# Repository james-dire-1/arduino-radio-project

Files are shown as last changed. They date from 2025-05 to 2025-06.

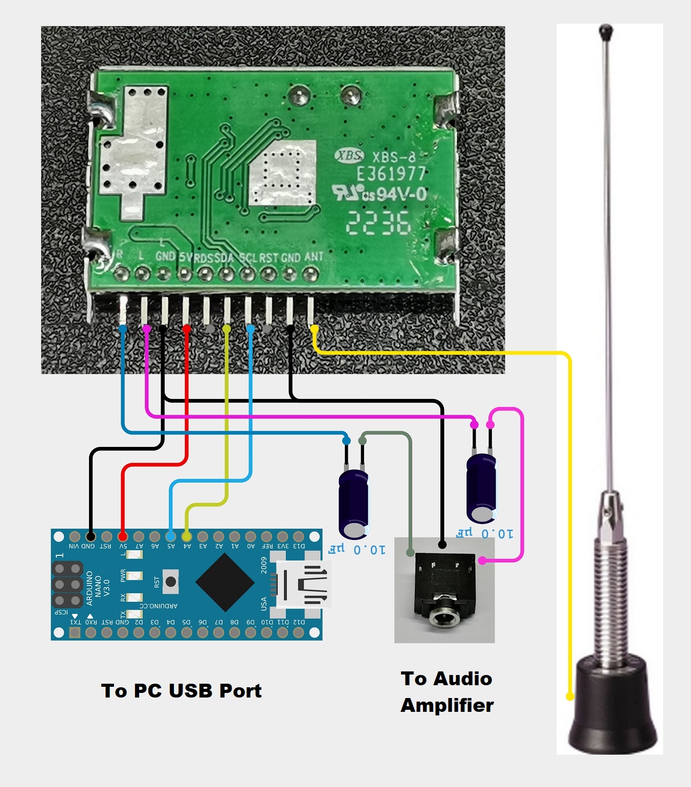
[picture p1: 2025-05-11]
R_other/schematic_final_WVFZMbBmqV.jpg

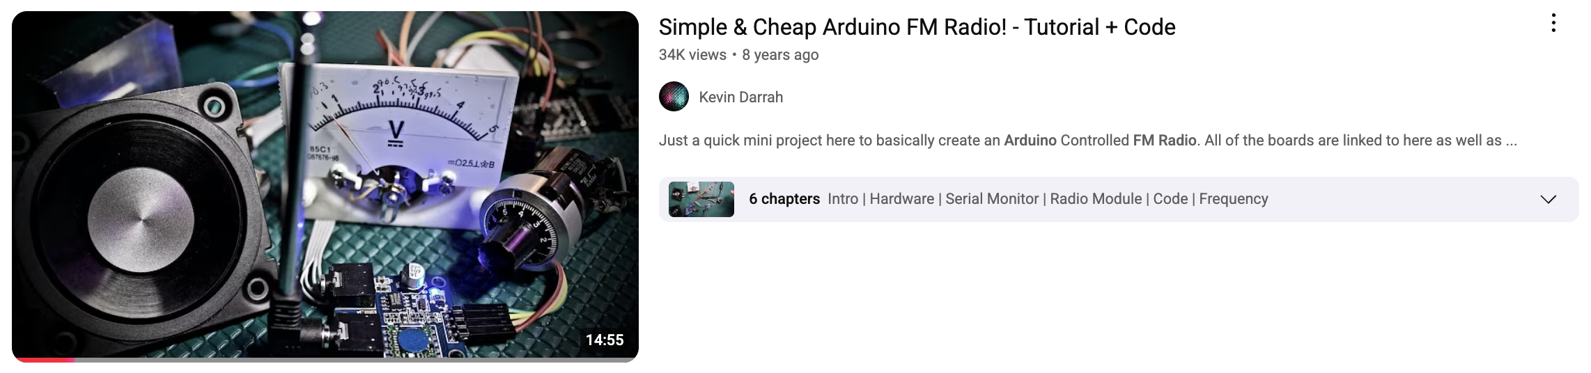
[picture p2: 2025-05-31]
R_other/SlideshowImages/Screenshot 2025-05-30 at 10.30.26 AM.png

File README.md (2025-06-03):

# Arduino Radio

The Arduino Radio is an FM radio built for the Dawson College MakerSPACE Internship as a
semester-long project. It contains an LCD display for displaying band and frequency, supports preset saving and tuning, and is packaged in a small, portable box so that it can be brought around easily. 

## Overview and Features

- Powered by a rechargeable power bank
- Frequency tuning via a rotary encoder
- LCD display for displaying current band and frequency
- Volume control
- Two speakers
- Preset saving
- Last tuned station saved for next power up
- Telescopic antenna
- Green and blue box, with black backplate

## Project Structure

```
arduino-radio-project/
│
├── src/             # Where the code is located
├── R_resources/     # Important resources
├── R_images/        # Images of the final radio
├── R_finalreport/   # The final report for the project
├── R_assignments/   # Formal assignments done for the project (and their iterations)
├── R_slideshow/     # Slideshow for the presentation from May 30th, 2024
├── R_models/        # 3D models for the radio
├── R_oldcode/       # Old iterations of code before version control
├── R_other/         # Miscellaneous files; unimportant
├── R_todo.txt       # General todo list
├── LICENSE          # MIT License file 
└── README.md        # This file
```
There are other files/folders too which were generated by PlatformIO, an extension that enables Arduino support in VSCode, which aren't listed here.

Also, in some of the above folders, there is a `README.txt` file which details all the files/other folders found in that folder.

## Getting Started

Below are instructions for getting the radio working yourself, if you wish.

### Prerequisites

- Visual Studio Code
- The [PlatformIO extension](https://platformio.org/) for VS Code installed
- The libraries outlined below in [Libraries Used](#libraries-used)
- All the necessary hardware (this can be found in [`R_resources/HardwareLinks.txt`](R_resources/HardwareLinks.txt); look under the section MAIN HARDWARE)

### Installation

```
# Clone the repository
git clone https://github.com/james-dire-1/arduino-radio-project.git

# Navigate to project directory
cd arduino-radio-project
```

### Setting things up

⚠️ WARNING: This project overwrites some sections of Arduino EEPROM. Make sure you have nothing important saved in the memory addresses indicated in the code. Also, make sure that the amplifier volume knob is turned down to not have any surprise loud noises on power up.

First, set up the radio circuit as detailed in the circuit diagram (this can be found in [`R_resources/CircuitDiagram.png`](R_resources/CircuitDiagram.png)).
Upload the code onto the Arduino via the Upload tool provided by PlatformIO.
The radio is now ready to go!

### How to use

Extend the antenna for optimal reception. (Although, the radio should still work fine even if the antenna is not extended; it even works without the antenna!)

Use the rotary encoder to switch between frequencies.

Use the joystick to change between presets. Up, down, left, and right correspond to different presets.

Use the knob on the amplifier to change the volume. (But don't raise the volume too high, as audio distortion occurs at high volumes.)

Hold down on the rotary encoder for a few seconds to overwrite any preset. Once the scrolling prompt appears, move the joystick in the direction of the preset you wish to overwrite.

Congratulations, you are now an expert user of the Arduino Radio!

## Advanced Section!

If you would like to package your radio into a portable box, there are model files that can be 3D printed which are found in [`R_models/`](R_models/). However, it is recommended that you design your own box for the radio components, as the designs provided in the model files have many flaws and problems to them.

## Libraries Used

### For LCDs
- [hd44780](https://github.com/duinoWitchery/hd44780/tree/master) by Bill Perry. Contains functions like `setCursor(0, 0)`, `print("")`, and `clear()`

### For rotary encoders
- [RotaryEncoder](https://github.com/mathertel/RotaryEncoder/tree/master) by Matthias Hertel. Contains functions like `tick()` and `getDirection()`

### Extra snippet of code
Also, a snippet of code from Kevin Darrah's YouTube video (linked below in [Videos for inspiration](#videos-for-inspiration)) was used for this project. This code is pasted directly into the RadioModule class. Kevin Darrah mentions in the video that this snippet of code came from Simon Monk's library 
(linked further below).

## Final Report

A final report was written for this project. It can be found in [`R_finalreport/RadioFinalReport.md`](R_finalreport/RadioFinalReport.md).

## License

This Arduino radio project is licensed under the [MIT License](LICENSE).

## Acknowledgments

### Websites for inspration
- [Simple TEF6686 Arduino + PC AM-FM Radio Receiver](https://www.instructables.com/Simple-TEF6686-Arduino-PC-AM-FM-Radio-Receiver/)
- [All Band Receiver With SI4732 / SI4735 (FM / RDS, AM and SSB) With Arduino](https://www.instructables.com/All-Band-Receiver-With-Si4735-FM-RDS-AM-and-SSB-Wi/)

### Videos for inspiration
- [Building a MIDI Controller Using Arduino](https://www.youtube.com/watch?v=JZ5yPdoPooU&t=654s)
- [Make your own FM Radio - Part 1](https://www.youtube.com/watch?v=RqyhvlMKt14) 
- [How To Make FM RADIO using Arduino | TEA5767](https://www.youtube.com/watch?v=Xy7k_ZvcVhU) 
- [Simple & Cheap Arduino FM Radio! - Tutorial + Code](https://www.youtube.com/watch?v=n1hPj2wfsnA) 

### Instructional videos and links used
- [How I2C Communication Works and How To Use It with Arduino](https://www.youtube.com/watch?v=6IAkYpmA1DQ)
- [Using LCD Displays with Arduino](https://www.youtube.com/watch?v=wEbGhYjn4QI)
- [Using Rotary Encoders with Arduino](https://www.youtube.com/watch?v=V1txmR8GXzE)
- [ROTARY ENCODER WITH INTERRUPTS - Arduino tutorial #12](https://www.youtube.com/watch?v=gPLpPFmv-Zc) (not really used)
- [Pin Change Interrupts](https://gammon.com.au/forum/?id=11488&reply=6#reply6) (not really used)
- [Powering Arduino With a Battery](https://www.instructables.com/Powering-Arduino-with-a-Battery/)
- [How to program Arduino with VSCode](https://www.youtube.com/watch?v=gQ2lsSuXvVU)
- [A guide to EEPROM](https://docs.arduino.cc/learn/programming/eeprom-guide/)
- [C++ Tutorial Series](https://www.youtube.com/playlist?list=PLlrATfBNZ98dudnM48yfGUldqGD0S4FFb)

## Plans for Future Expansion

At the moment, there are no plans for future expansion. However, if we do come back to it (of which there is a fair chance of happening), we will attempt to add support for the features that we didn't get the chance to add throughout the semester, which include:

- AM and shortwave support
- Station scanning
- RDS (allows for printing of song title and station name)
- Bluetooth connectivity (so you can listen to songs from your phone, if you don't like whatever is playing on the radio for whatever reason)
- A settings screen with various options for audio
- More presets!

## Libraries We May Consider Using

There exist some libraries that could be useful for the future expansion.

### For TEA5767 FM module
- [Radio by Matthias Hertel](https://github.com/mathertel/Radio) 
- [arduino_TEA5767 by Simon Monk](https://github.com/simonmonk/arduino_TEA5767) 

### For TEF6686 AM and FM module
- [TEF6686Library by ciuri](https://github.com/ciuri/TEF6686Library) (seems to be particularly useful!)

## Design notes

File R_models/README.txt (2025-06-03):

This folder is for all 3D model files of the radio.

Files in this folder (R_models):

Any stl file prefixed with "Old..." in this folder is an old model file for only one face of 
the radio.

Main_box_assembly_part.SLDPRT
    File that was used to combine five different faces from the files prefixed with "Old..."

Main_box_assembly.SLDASM
    Edits on the Main_box_assembly_part.SLDPRT file.

radio_case_assembly.SLDASM
    Edits on the Main_box_assembly_part.SLDPRT file.

Main_box_assembly_part.STL
    The file that was used to print with the 3D printer. If you want to print from one of
    our models (and not make your own) should you want to make the radio yourself, it is
    recommended that you print from this file specifically.

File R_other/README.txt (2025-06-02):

This folder is for miscellaneous files that are related to the radio project, and are only in
this repository for completeness' sake.

Files and folders in this folder (R_other):

schematic_final_WVFZMbBmqV.jpg
    Schematic file we were considering using with the TEF6686 radio module.
    From https://www.instructables.com/Simple-TEF6686-Arduino-PC-AM-FM-Radio-Receiver/ 

ArduinoIdeas.txt
    Notes document used very early on in the project to organize ideas. This file was created
    before the radio idea was decided upon, so there are also other ideas listed.

Radio.ino.txt
    Code from Kevin Darrah's YouTube video https://www.youtube.com/watch?v=n1hPj2wfsnA, which 
    was used mostly as-is for this project. This video also served as inspiration for this
    project. In the video, Kevin Darrah mentions that this specific snippet of code was from
    Simon Monk's TEA5767 library (linked in this repsoitory's README).

ArduinoHardwareInstructions.docx
    Instructions document made so that everyone in the team would know how to wire up the
    radio components.

SlideshowImages/
    Folder of the images that were used in the slideshow found in R_slideshow.

CircuitDiagramImages/
    Folder of images used for the circuit diagram found in R_resources. Also contains the links 
    to all images in the circuit diagram.

ProgressVideos/
    Videos sent by James to the rest of the group when various progress throughout the semester
    was made. Real professional-grade videos with exceptional production quality. Also includes
    a couple of videos recorded by Claudio in the physics lab showcasing the radio working.

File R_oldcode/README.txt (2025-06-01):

This folder is for old iterations of the radio code that existed before version control for the
project was set up. They are presented in this folder for completeness in the documentation of
this project.

Folders in this folder (R_oldcode):

RadioIdeas
    Old project folder from the Arduino IDE from March 16.

RadioIdeas2
    Old project folder from the Arduino IDE from May 1.

RadioIdeas4_1
    Old backup folder from the Arduino IDE from May 8. This backup mostly separated the code into
    multiple files.

RadioIdeas4
    Old project folder from the Arduino IDE from May 10.

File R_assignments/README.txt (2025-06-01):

This folder is for assignments that needed to be submitted (and some of their in-progress 
iterations).

Files in this folder (R_assignments):

project-proposal_DiRe-Scione-Kikia.docx
    The original project proposal outlining the team's project of building an Arduino radio.
    Submitted by March 10th.

OLD_Arduino_Report.docx
    First iteration of the final report.

1_ArduinoReport.docx
    Second iteration of the final report.

2_ArduinoReport.docx
    Third iteration of the final report.

ArduinoReport.docx
    Last iteration of the final report before it was transferred to a Markdown file. The
    most up-to-date report can be found in R_finalreport.

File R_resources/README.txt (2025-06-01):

This folder is for important resources. Most of these resources will be linked from the 
main README file.

Files in this folder (R_resources):

HardwareLinks.txt
    Comprehensive list of hardware for the project along with respective links.

CircuitDiagram.png
    Complete circuit diagram for building the radio. Made with LucidChart.

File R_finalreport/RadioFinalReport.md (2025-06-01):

James R. Di Re, Abdulrahman Kikia, Claudio Scione

June 1<sup>st</sup>, 2025

MakerSPACE Internship

# Arduino Radio - Final Report

## Introduction

In this report, we will detail the brainstorming, designing, programming and building of our MakerSPACE internship project: an Arduino-powered FM radio. Over the course of the past three months, we have worked to put together a working radio while documenting the entire process to serve as an inspiration and as a guide to anyone else who may want to embark on a similar project. Our goal when choosing this as our project was not only to improve our programming and debugging skills through a hands-on approach, but also to gain an understanding of radio waves, audio processing, and speakers. All this, in addition to enjoying the satisfaction of listening to music and news from local radio stations through a compact device we made from scratch.

## Project Description

### Objective

The goal of this project was to build a working AM/FM radio, using the Arduino Uno as the microcontroller and the Arduino IDE to write the code. We aimed to not only have it be able to play music through speakers, but also to display information about the frequency and station (RDS) on a digital display. Finally, we wanted to design and build a casing to insert all the hardware into that was practical and portable. While this was the base goal of this project, we hoped to add as many features as possible to the radio within the time frame we had to complete this project. We hoped to add a function to save preset radio stations that you could choose and change as you wished, shortwave compatibility, radio station scanning and even Bluetooth connectivity.

### Inspiration

It was James who originally came up with the idea of making a radio using Arduino. He knew initially that he wanted to do something involving audio, since he always enjoyed working with music and had a fascination with how sound waves worked. At first, he looked through many different audio projects, such as synthesizers, MIDI controllers, and distortion-altering guitars, but there was one common problem with all of these projects: none of us knew anything regarding these topics. Eventually, he saw a few videos on YouTube of people using Arduinos to make working radios. A radio project seemed more feasible than other audio projects he had seen, since everyone in the team was familiar with how radios worked. However, the videos used FM-only radio modules, and only detailed the wiring process. We decided it would be interesting to expand on those projects James had seen online to make a radio with more features and a case to enclose it in. After some research on the Arduino forums, Instructables, and other project sites, we saw other examples of radios, each with their own unique construction and design. That made us realize that this was something we could realistically build and design on our own in the months we had to work on this project. Plus, the fact that the radio was practical (we could listen to music and news from it everyday) and intuitive (you can pick up radio signals anywhere) solidified our decision.

### Design and Planning

For the design, we wanted to build a radio that was reminiscent of old-school radios. That is, we wanted to use knobs instead of buttons. We also wanted it to be unique with some asymmetry. We shared different sketches of the design and some concept 3D renders to see where our imagination could go. In the end, we couldn’t settle on a specific design until we got all parts working and tested.

Much research was done early on to figure out the exact parts we were going to need. Also, the sheer number of available radio modules to pick from was overwhelming. However, one common theme between the videos we had initially watched was that most of them used the TEA5767 FM-only module, so we decided to get that in case other modules didn’t work the way we wanted them to. It was a logical decision, since if many others had success with it, then we should have success with it too. However, our initial goal was to have an AM/FM radio, with possible support for shortwave too, so we continued looking for more radio modules. After some more research, we were leaning towards the Si4732, which seemed to be very advanced and had many features to it. However, upon digging deeper, we realized that this “radio module” was nothing more than an extremely tiny chip; no breakout board for ease-of-use with Arduino existed. Thus, we had to keep looking.

An easy-to-use AM and FM radio module seemed to be nonexistent, but then James saw a YouTube video of an AM and FM Arduino-powered radio, so then we realized that one must exist. This new video we found pointed us in the direction of the TEF6686 module. This had most of the advantages of the Si4732 but had a sort of breakout component that could be used with our Arduino, with the help of pitch changers. However, there were less chances of this module being successful for us, since there were less people online who had used it, there was overall less documentation for it, and the pinout seemed a lot more complicated compared to that of the TEA5767 (we found only a single circuit diagram explaining how the pinout worked). So, we decided that we would try first with the TEA5767, and if we had time, we would try the TEF6686.

Designing a case to house all the parts also proved to be a challenge. The setup out of the case functioned well, but was fragile in the initial phases. The speaker wires kept disconnecting from the amplifier with the slightest movement, thus causing the speakers to stop playing, even after tightening the screws to hold the wires in place. To fix this, a thicker wire was soldered onto the thinner speaker wire. There were also pieces that would have to be mounted to the front of the case, so that the user could interact with the radio as intended. This was particularly problematic for the speakers, since they didn't have screw holes. Also, their wires could interfere with the screen if the positioning wasn’t optimal. However, the screen, antenna, and rotary encoder had screw holes, so mounting them wouldn’t be an issue. We made a prototype using cardboard to see how the pieces would go together. With the prototype, we attempted to make measurements for where each of the components would go, and then Abdulrahman incorporated these measurements in the modelling software he was using by adding holes to the box design where necessary. 

Initially the idea was to have the six faces of the box snap into each other through connectors that were meant to hold them by pressure. However, as the faces would break with high pressure, we had to change the design so that five faces would be permanently attached (one only would be detachable). 

As for our power source, we planned out different options. We thought of using a 9-V battery, but the connector that the battery used was very stiff and didn't come easily out of its terminals, so removing the battery wasn’t a feasible option to cut the circuit. After trying different options, we ended up using a power bank, as it can be easily removed and charged when needed. 

The result of all this planning was a radio that was fairly portable, and was comparable to other radios of its kind in size.

## Implementation

### Hardware Setup

#### Hardware List

- Arduino Uno microcontroller
- Rotary encoder with button - for frequency tuning
- LCD display that is I<sup>2</sup>C compatible - for displaying radio data
- TEA5767 FM radio module with antenna - for receiving radio signals
- TDA7297 amplifier - for amplifying the audio signal coming from the radio module and for allowing volume control
- Male-to-male headphone wire - for sending the audio signal from the radio module to the amplifier
- Speakers
- Joystick - for choosing between different preset stations (up, down, left, right = 4 presets)
- Power source: power bank OR 9-V battery OR power from a computer
- Male-to-male jumper wires
- Male-to-female jumper wires
- Breadboard

#### Circuit Diagram

Circuit Diagram

### Software Development

#### Process

Firstly, James already had C++ knowledge from a tutorial series he had watched on YouTube a few years ago by The Cherno, so because of that, it was a lot easier for him to write code for the project compared to someone just starting out. However, this was still his first time putting that knowledge into real practice. James recommended to the other group members that they watch some videos from the tutorial series too. 

The features in the code were at first programmed in the Arduino IDE, and were added gradually (for example, first the code for the rotary encoder and LCD display were added, then the code for the radio module, then the code for the joystick, then the code for preset-saving, etc.). The code was always kept in a maintainable condition that was simple to expand upon. This was a top priority, as James knew from past projects that untidy code gets exponentially hard to maintain. Eventually, even though the code was kept organized, it was still overwhelming to keep all the functionality in one file. Thus, it was separated into six separate files: the main cpp file, a main header file, a class for managing radio state, a class for handling input, a class for handling the LCD display, and a class for handling the radio module. Later on in development, this proved to be a great choice, as each of these files grew in size. Looking back, it would not have been feasible to have kept everything in a single file. 

However, separating the code into different files didn’t come without its own problems. For one thing, there were many bugs that got introduced as a result, and all of them were isolated to being issues regarding C++’s copying of objects in unexpected areas. As a result, in fixing these bugs, the team grew more familiar with C++’s copying conventions, and became more aware of when it was appropriate to use pointers (`*`) or references (`&`).

Eventually, the entirety of the code was moved to Visual Studio Code. This provided many advantages over the Arduino IDE. For one thing, VS Code allowed for easy integration with version control software such as Git and GitHub. Also, it underlined compilation errors in real-time, a feature which the Arduino IDE lacks entirely. There were also refactoring tools and an easy way to view the project structure. The extension used that introduced Arduino compatibility in VS Code was PlatformIO. A GitHub repository for the project was created.

Once everything was in VS Code, all the old iterations of code we had which were not under version control were pushed to the GitHub repository in a separate folder. This was in an effort to document everything we could. However, all new code added to the project was properly pushed to GitHub in the proper fashion, with frequent commits.

New functionality for the radio kept getting added until just a few days before the MakerSPACE presentation on May 30<sup>th</sup>. Once the code was entirely done, James looked through all of it one last time to see if any little details could be improved upon, then committed and pushed the changes. This was the code iteration that was used in the in-class demo. 

#### Libraries

As for libraries, a couple of them were used. First, there was `hd44780` by Bill Perry, an LCD library using I<sup>2</sup>C communication, which was exactly what we needed, since the LCD screen we had purchased supported I<sup>2</sup>C communication through a little board on the back. Also, this library was supposedly more up-to-date and compatible with more LCD models than other libraries, even those that had been around for a long time. Since this library was meant to be easy-to-use for those that were already familiar with other, more-established LCD libraries, many of the function names matched those from other libraries. Some useful functions include `setCursor(int, int)`, `print(“”)`, and `clear()`.

The other library that was used was `RotaryEncoder` by Matthias Hertel. This library saved us a lot of headache, since it removed the problem of trying to find a good way to read the quickly changing voltages from the data and clock pins on our rotary encoder to determine the direction of turning. Also, all code that I had seen for this task was flawed in some way. Thus, this library did a lot of the heavy lifting for us. However, one minor issue with it was that input needed to be polled very frequently in order to catch all turns done on the rotary encoder. This meant that we had to ensure that our `loop()` function was kept short, and was short to execute. Sometimes, during debug sessions where we had `Serial.println()` calls scattered throughout the code, the rotary encoder would become completely unresponsive. Nonetheless, the library did get the job done. Some useful functions include `tick()` and `getDirection()`.

Also, although not really a library, a snippet of code from one of Kevin Darrah’s YouTube videos was used, which communicated desired frequency values to the radio module. This code was pasted directly into our code, and was left mostly as-is. Kevin Darrah mentions in his video that the code is from a TEA5767 library by Simon Monk.

An important reference that helped us frequently was the official Arduino documentation. For instance, everything we needed to know about EEPROM was included in the documentation, and was presented in a clear, concise manner. In addition, as mentioned earlier, the YouTube tutorial series by The Cherno was occasionally consulted throughout development.

### Sensor Documentation

- TEA5767 Radio Module

The radio module picks up FM radio signals. Signal reception is improved when an antenna is attached. To communicate with the radio module, which uses I<sup>2</sup>C, we need to use the Arduino `Wire` library. 

The following is the code provided by Kevin Darrah in his YouTube video (mentioned earlier) to communicate with the radio module to change stations. 

```arduino
void setFrequency(float frequency)
{
  // The calculation that needs to be performed before sending the frequency is outlined in the datasheet for the TEA5767
  unsigned int frequencyB = 4 * (frequency * 1000000 + 225000) / 32768;
  
  // Getting the high byte of the modified frequency
  byte frequencyH = frequencyB >> 8; 
  // Getting the low byte of the modified frequency
  byte frequencyL = frequencyB & 0XFF; 

  Wire.beginTransmission(0x60); // Begin communication with the radio 
  Wire.write(frequencyH); // Writing high byte
  Wire.write(frequencyL); // Writing low byte

  // The following three bytes that are written correspond to a set of parameters being sent to the radio module. Generally, each bit indicates a setting for the radio module to follow. The exact details of each bit in each byte are found on the datasheet.
  Wire.write(0xB0);
  Wire.write(0x12);
  Wire.write(0x00);

  Wire.endTransmission(); // End communication
  delay(100);
}
```

- TDA7297 Amplifier

The amplifier detects sound signals (from the radio module) and transmits them to the speakers. It also has a potentiometer that controls the power given to the speaker (the volume coming out of them).

- Rotary Encoder

The rotary encoder helps with navigating radio frequencies. Each step in the rotation gives the Arduino a signal to either increase or decrease the frequency picked from the radio module by 0.2 MHz, which is the standard for radio stations in Montreal. The rotary encoder works by taking into account the voltage patterns over time across the data wire and the clock wire. With this information, we can deduce which way the rotary encoder is being turned. However, the way to deduce this is slightly complicated, so a rotary encoder library is used. 

Code to initialize a `RotaryEncoder` object with the `RotaryEncoder` library:

```arduino
// PIN_A and PIN_B refer to the clock and data lines of the rotary encoder. If the rotary encoder behaviour is opposite to what you expect, just switch these pins in the constructor.
RotaryEncoder encoder(PIN_A, PIN_B, RotaryEncoder::LatchMode::FOUR3);
```

Code to poll rotary encoder input (should be called every time `loop()` is run):

```arduino
encoder.tick();
```

Code to get the direction that the rotary encoder has turned:

```arduino
// Returns 0 if not turning, 1 if clockwise, -1 if counterclockwise
int direction = encoder.getDirection();
```

- Joystick

The joystick has two potentiometers for dual axis rotation. It can detect the rotation of the stick in a continuous manner (but only four directions with precision) and in our case is the optimal way to select and tune in on presets. Input is read via the analog pins.

Code for reading in the x and y values of the joystick, which range from 0 to 1023:

```arduino
int rawX = analogRead(PIN_X);
int rawY = analogRead(PIN_Y);
```

Code to convert these values to those that are between -1 and 1, which are a lot easier to work with:

```arduino
float x = (rawX / 1023.0f) * 2 - 1;
float y = (rawY / 1023.0f) * 2 - 1;
```

## Results

At the end of the project, we had a functional radio that was capable of tuning to FM radio stations for extended periods of time, which made it practical for everyday use. In addition, the audio quality was not bad at all. The rotary encoder for changing between stations worked without any problems. The LCD display also showed relevant information, such as band, frequency, and preset number without any problems. We did manage to get preset-tuning and preset-saving to work with the joystick in the last week or two leading up to the final MakerSPACE presentation, although there were some problems involving it (explained a bit later). Also, throughout the development process, up until the end, the code was still well organized, and didn’t get too untidy.

However, there were some persisting issues that lasted until the end of the project. For one thing, every time the LCD screen updated, interference could be heard through the speakers (a static sound). This was not really noticeable when the screen contents changed periodically, but whenever the contents changed frequently (such as when text was scrolling), it would become really noticeable. We were never able to fix this. In addition, there was a similar type of interference issue with the joystick. Whenever moving the joystick (especially in the direction defined as preset 2 in our code), a loud buzzing noise could be heard, and would continue to play until the joystick was let go.

In addition to that, the joystick for some reason interfered significantly with any I<sup>2</sup>C communication, and we never figured out why. We tried including capacitors in our circuit to regulate the problem, but they didn’t have any effect on the issue. Since the joystick would interfere with I<sup>2</sup>C, sometimes missing or strange characters would appear on the LCD screen or the code would freeze. We knew the code froze because we sprinkled our code with `Serial.println()` calls to isolate the issue, and at one point, it would stop printing at a `Serial.println()` call that was right before any `Wire`-related Arduino function. To confirm that it was the joystick causing the problem (and not some other component), we changed the code to switch radio stations every one second instead of changing them via the rotary encoder, and commented out all code involving the joystick. However, we still kept the joystick connected. Under these conditions, whenever the radio station would stop switching, it would always happen when the joystick was being moved around.

Another problem with the radio was that the volume knob couldn't be turned all the way, or very bad distortion would occur.

As for the box, many compromises after printing had to be made. According to Claudio (who printed part of the radio box at his house and whose brother’s friend printed another part at his house), most of the measurements that we had made for fitting everything in the box were wrong. This meant that he and his brother had to come up with creative solutions for getting everything in the box. For instance, our radio’s handle holes (holes at the top to easily hold the radio) turned out to be the holes through which the antenna and Arduino ports were accessible, as the real holes we made for them were not positioned properly. In addition, the breadboard didn’t fit lying flat on the radio’s floor, which was the initial plan, so it had to be placed sideways against the back. Also, the little shelves that were made to place the speakers on were not positioned properly, and so they had to be broken off. Lastly, although our initial plans were to screw all the components in, we ended up hot gluing most of them instead to save on time. To save on more time, the print job was done at twice the intended speed so that the box would be ready on presentation day. This resulted in a battered-up box. However, despite all these drawbacks, the radio was still entirely functional.

### Comparing with Initial Objectives 

Compared to the initial objectives, there were some features that were not achieved for the final product. For instance, the final radio did not support AM or shortwave bands, since we did not have time to try out the TEF6686 radio module, which supported these features. There was also no radio station scanning, RDS, or Bluetooth connectivity. Also, since there wasn’t enough time to design a PCB for the components, we had to stick to the breadboard, which took a lot of space inside the box. Besides these lacking features though, everything else we had planned on was included.

### Discussion and Conclusion

Overall, the project was a lot of fun to work on, and we learnt a lot throughout the semester, such as how to use Git and GitHub, libraries, VS Code, C functions like `sprintf()`, and EEPROM. Also, we learnt how to package components into a box. By the end, we were really excited that we had created our very own radio. 

Most of the successes occurred early on in the project, when we were testing the radio features before packaging everything in a box. Adding more code and testing it went mostly smoothly. We think this was because (like mentioned earlier), James already had prior C++ knowledge before starting the project. Plus, Abdulrahman had also been learning Python on his own for some time, and Claudio learnt some programming in the engineering physics class, so all of us had the knowledge necessary to think in a logical, problem-solving manner. 

Many of the challenges occurred much later in the project, mostly in the last week leading up to the presentation, which was the week when the final box was designed, printed, and altered. None of us had printed 3D models made to house various components that needed to interact with each other before, so we guessed that this part was going to be challenging. Our guess was correct, as many last-minute changes and compromises had to be made due to the bad measurements we had taken. However, while running into mistakes due to measurements is normal, as many of the placements were eyeballed, what really affected us the most was the limited time to print the enclosure and adjust the measurements. There was basically no time to print multiple versions and get the optimal radio enclosure to house all the parts in a neat way, which even the most skilled mechanical engineers would do. So for a first version that was printed in half the required time, it still managed to hold all of the components, and even had a unique look.

Once again, at the beginning of the Winter 2025 semester, we had set an objective for ourselves to build a portable AM and FM radio that included features such as preset-saving, scanning, RDS, and Bluetooth compatibility. The idea to build a radio came from James wanting to do a project involving audio and from watching many YouTube videos of others building Arduino radios. Then, throughout the course of the semester, we gradually obtained more and more hardware to continue expanding upon our radio, adding features as we went. As more features were added, the codebase was split into separate files to maintain control, organization, and scalability. Libraries also facilitated the development process. By the end of the project, we had built a fully functional Arduino radio. Although it did not include every feature that we had planned to implement, we were still really proud of what we created. Not only that, but we also gained much knowledge and skill that can be applied for future projects.

Some possible improvements for the project include those already mentioned that did not make the final build (i.e. AM, shortwave, scanning, RDS, Bluetooth compatibility). In addition, it could be interesting to experiment with different box designs, such as one made out of wood. Potentially, it would be interesting to make the whole chassis thinner and more organized internally by designing a custom PCB. Moreover, we are curious as to how we would go about making a settings menu that supported changing audio settings, such as bass, treble, etc. We’re not sure as to how we could get that to work, since it seems like achieving this feature would mean routing the audio signal through the Arduino, which doesn’t seem feasible since we don’t think the Arduino can process audio signals fast enough for them to still be perceived as good sound, but the idea is still interesting nonetheless.

### References

#### Link to the repository:

https://github.com/james-dire-1/arduino-radio-project 

#### Libraries:

[1] Bill Perry, “hd44780: Extensible hd44780 LCD library,” _GitHub_, 2016. https://github.com/duinoWitchery/hd44780/tree/master (accessed Jun. 01, 2025).

[2] Matthias Hertel, “RotaryEncoder: RotaryEncoder Arduino Library,” _GitHub_, Jul. 18, 2022. https://github.com/mathertel/RotaryEncoder/tree/master (accessed Jun. 01, 2025).

#### Inspiration sources:

[1] mircemk, “Simple TEF6686 Arduino + PC AM-FM Radio Receiver,” _Instructables_, Mar. 31, 2023. https://www.instructables.com/Simple-TEF6686-Arduino-PC-AM-FM-Radio-Receiver/ (accessed Jun. 01, 2025).

[2] pu2clr, “All Band Receiver With SI4732 / SI4735 (FM / RDS, AM and SSB) With Arduino,” _Instructables_, Mar. 26, 2020. https://www.instructables.com/All-Band-Receiver-With-Si4735-FM-RDS-AM-and-SSB-Wi/ (accessed Jun. 01, 2025).

[3] Switch & Lever, “Building a MIDI Controller Using Arduino,” _YouTube_, Dec. 03, 2019. https://www.youtube.com/watch?v=JZ5yPdoPooU (accessed Jun. 01, 2025).

[4] GreatScott!, “Make your own FM Radio - Part 1,” _YouTube_, Mar. 06, 2016. https://www.youtube.com/watch?v=RqyhvlMKt14 (accessed Feb. 13, 2024).

[5] EDISON SCIENCE CORNER, “How To Make FM RADIO using Arduino | TEA5767 | giveaway results,” _YouTube_, Aug. 16, 2024. https://www.youtube.com/watch?v=Xy7k_ZvcVhU (accessed Jun. 01, 2025).

[6] Kevin Darrah, “Simple & Cheap Arduino FM Radio! - Tutorial + Code,” _YouTube_, Dec. 17, 2016. https://www.youtube.com/watch?v=n1hPj2wfsnA (accessed Jun. 01, 2025).

#### Instructional/learning resources:

[1] How To Mechatronics, “How I2C Communication Works and How To Use It with Arduino,” _YouTube_. Oct. 05, 2015. Accessed: Jun. 01, 2025. [YouTube Video]. Available: https://www.youtube.com/watch?v=6IAkYpmA1DQ 

[2] DroneBot Workshop, “Using LCD Displays with Arduino,” _YouTube_. Mar. 19, 2018. Accessed: Jun. 01, 2025. [YouTube Video]. Available: https://www.youtube.com/watch?v=wEbGhYjn4QI

[3] DroneBot Workshop, “Using Rotary Encoders with Arduino,” _YouTube_, Mar. 23, 2019. https://www.youtube.com/watch?v=V1txmR8GXzE (accessed Jun. 01, 2025).

[4] amandaghassaei, “Powering Arduino With a Battery,” _Instructables_. https://www.instructables.com/Powering-Arduino-with-a-Battery/ (accessed Jun. 01, 2025).

[5] Abstract programmer, “How to program Arduino with VSCode,” _YouTube_, Aug. 13, 2022. https://www.youtube.com/watch?v=gQ2lsSuXvVU (accessed Jun. 01, 2025).

[6] “A guide to EEPROM,” _Arduino Docs_, Jun. 19, 2024. https://docs.arduino.cc/learn/programming/eeprom-guide/ (accessed Jun. 01, 2025).

[7] The Cherno, “C++ Series,” _YouTube_. https://www.youtube.com/playlist?list=PLlrATfBNZ98dudnM48yfGUldqGD0S4FFb (accessed Jun. 01, 2025).

### Acknowledgements

Thank you to Abdulrahman’s high school robotics team for allowing him to use software such as Onshape regularly, which allowed him to design the radio box himself.

Thank you to Claudio’s brother and his friend William for printing out our radio, and thank you again to Claudio’s brother for helping come up with solutions to the incorrect measurements we had made.

Thank you to all the instructional/learning resources and libraries listed above. Every one of them helped the radio project come to life.

Thank you to all the inspiration sources also listed above. Without them, we may not even have built a radio.

And a huge thank you to Joel Trudeau and Manuel Zapata for mentoring the MakerSPACE Internship, and thank you to Dawson College for covering some of the costs for hardware. The Friday meetings were really the highlight of the school week! ☺

And thank you to everyone who showcased their projects during the final presentation, effectively encouraging and inspiring everyone to continue working on electronics projects even after the internship concluded.

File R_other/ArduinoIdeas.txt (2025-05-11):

Arduino ideas

// MIDI Controller
// Synthesizer Module
// Posture Corrector
// Stress Level Monitor
Radio
// Water quality thing

Arduino GIGA Wavetable Synthesiser
https://projecthub.arduino.cc/Arduino_Genuino/arduino-giga-wavetable-synthesiser-737364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 
Auduino - Lo-Fi Arduino Synthesizer
https://www.instructables.com/Auduino-Lo-Fi-Arduino-Synthesizer/ 

DIY ESP32 Internet Radio
https://projecthub.arduino.cc/zetro/diy-esp32-internet-radio-4353a4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..
A radio similar to this one seems interesting, but it would have to be modified to use the UNO

Arduino VFO Project with a Large LCD Display
https://projecthub.arduino.cc/mircemk/arduino-vfo-project-with-a-large-lcd-display-6f8e83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 
Doesn’t seem to be useful for us, but it seems like it is able to transmit radio waves, so maybe it might be interesting to look at?

Using Arduino to Test Your Water Quality
https://projecthub.arduino.cc/sharnat/using-arduino-to-test-your-water-quality-3c08dc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. 

BMP280: Measure Temperature, Pressure and Altitude
https://projecthub.arduino.cc/SurtrTech/bmp280-measure-temperature-pressure-and-altitude-6002cd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

SENSORS
1: Joystick
14: Touch sensor?
22: Button
26: Buzzer?
32: Passive buzzer?
34: Rotary encoder

NOTES- Apparently volume control can be handled directly on the amplifier

MAIN PARTS
Main microcontroller: Arduino UNO
Main radio module: Si4732
Speaker: 
Screen: LCD screen

On/off function: 
Volume function: 
AM/FM toggle function:
Tuning function:
Presets function:
Scan function:
Set presets function:

Amplifier: a 5-volt class D amplifier/TDA7297?
Internal volume manager: MCP4151 (potentiometer)
Storage for presets and last station: EEPROM which is built into the UNO (no SD card necessary)
Antenna: telescopic antenna

OTHER PARTS to consider but probably will not be used
Main radio module: TEA5767 (x3) - only supports FM
Amplifier: TDA1905 - too complicated to use

KNOBS
1-turn potentiometer
10-turn potentiometer

// VIDEOS
// https://www.youtube.com/watch?v=RqyhvlMKt14
// https://www.youtube.com/watch?v=n1hPj2wfsnA 

// Si4732
// Si4735
// TEA5767
// TEA5768
// TEF6686

——

Why It is better to use the TEF6686 instead of the Si4732:

Si4732 is actually just a chip. There are not really any modules that are available for our case.
Si4732 does have some breakout boards. At first, I thought these were the actual modules. Then, I realized that they were something that required a lot of soldering to get working. You can either get a breakout board for the Si4732 by looking at a GitHub instruction page and making one yourself, by getting it on PCBWay, or by buying it off a retailer already built.
Si4732 does seem to have some modules, but not any that are useful for our needs. One module already includes an Arduino Nano or something similar with it, which means the module is already a fully functional radio. Another one seemed to be promising, as it had an audio jack similar to the one seen on the TEA5767, but there was a space fitted specifically for an Arduino Nano or something similar, which was also not what we needed. A third one I saw looked like a module (at first I had thought it was a raw chip, but it wasn’t), but it was a module specifically for use with a specific type of walkie talkie from a specific manufacturer. I got suspicious of this when I noticed that the pin locations/soldering locations on the module didn’t even have any indications as to what each of them were for.

Also, if you manage to get one of those breakout boards for the Si4732, there seems to be a lot of work that needs to be done to get it to work with an Arduino. There seems to be a lot of crazy soldering and such. Also, the pin indications on the raw chip don’t even match nicely with the pin indications of the breakout board, which just added to the confusion. Also, the third-party library that is supposed to go with this chip seemed very intimidating to use, due to our inexperience. If we don’t want to use the library, then we would have to read through the data sheet, which is something I really don’t want to do (it is longer than both the TEA5767 and TEF6686’s data sheets). It didn’t seem right to base everything on our trusting the library, since we should have some understanding of what is going on, even if we are using a library. With the TEF6686 however, I found a library that seems straightforward to understand, and once it is understood, we could even understand more deeply the I2C protocol that takes place between the Arduino and the TEF6686. It also helps that the data sheet for the TEF6686 is much more simpler to understand, and is written in a very straightforward way. It is also really nice that the TEF6686 library is very lightweight; it only consists of a few files, so it doesn’t feel like we are leaving all of the work to the library in question.
Also, the schematic for setting up the Si4732 breakout board with the Arduino seems ridiculously complicated to understand. The schematic for setting up the TEA5767 module with the Arduino, and the schematic for setting up the TEF6686 module with the Arduino, seem very straightforward to use, and intuitively make sense in the context of I2C (the Si4732 schematic seemed to be all over the place and impossible to understand). Although the TEF6686 schematic does seem slightly more involved than the TEA5767 schematic, it is not by much.

One good alternative we could have used was the complete module of the Si4732 created by Sparkfun. It seemed to be a complete module and everything. Unfortunately (or fortunately, I don’t know yet), it got discontinued.

We might decide to implement our radio with the TEA5767 before trying out the TEF6686, just because there are already many examples online of people using the TEA5767 (such as in YouTube videos), and so there would be a lot of help and reference should we need it. Also, we already have perfectly working code from a YouTuber if we use the TEA5767; if we use the TEF6686, we would have to rely on the corresponding library at first, which we aren’t even sure would work. However, it would be great to switch to the TEF6686 eventually, just because it also supports AM, which the TEA5767 doesn’t.

Additional functions:

Continuous scan
Settings options
	continuous tuning
	about section
Additional AM/FM button, as pressing on the knob will just show more information

Links:

Websites for inspiration
https://www.instructables.com/Simple-TEF6686-Arduino-PC-AM-FM-Radio-Receiver/ 
https://www.instructables.com/All-Band-Receiver-With-Si4735-FM-RDS-AM-and-SSB-Wi/

Videos for inspiration
https://www.youtube.com/watch?v=JZ5yPdoPooU&t=654s 
https://www.youtube.com/watch?v=RqyhvlMKt14 
https://www.youtube.com/watch?v=Xy7k_ZvcVhU 
https://www.youtube.com/watch?v=n1hPj2wfsnA 

Instructional videos and links
https://www.youtube.com/watch?v=6IAkYpmA1DQ 
https://www.youtube.com/watch?v=wEbGhYjn4QI 
https://www.youtube.com/watch?v=V1txmR8GXzE 
https://www.youtube.com/watch?v=gPLpPFmv-Zc 
https://gammon.com.au/forum/?id=11488&reply=6#reply6 

Instructables
https://www.instructables.com/Powering-Arduino-with-a-Battery/ 

Libraries
TEA5767
https://docs.arduino.cc/libraries/radio/?fbclid=IwAR0RHHBBque7rx_zP_Ns2fzSN8FPqqi5Pc9K1L9mtPytmW70RFdRn7JaiW4 
https://docs.arduino.cc/libraries/arduinotea5767/ 
TEF6686
https://github.com/ciuri/TEF6686Library 
Miscellaneous
https://github.com/RTVDXRO/TEF6686-AM_FM_RDS-Radio/blob/master/UserManualTEF668X.pdf 
https://github.com/jgromes/RadioLib 
For LCDs
https://github.com/duinoWitchery/hd44780/tree/master 
Rotary Encoders
https://github.com/mathertel/RotaryEncoder/tree/master 

Radio modules
https://www.amazon.ca/76-108MHZ-TEA5767-Stereo-Module-Antenna/dp/B074TC3VLN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 
https://www.amazon.ca/Radio-Module-Main-chip-TEF6686/dp/B0DXF17PTN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 

Amplifiers
https://www.amazon.ca/DEVMO-TDA7297-Digital-Amplifier-Channel/dp/B07T5L5GY4 
https://www.amazon.ca/Willwin-PAM8403-Digital-Stereo-Amplifier/dp/B075ZR6QNX 
https://www.amazon.ca/Ganasome-Times-LM386-Amplifier-Module/dp/B0CW193LVD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

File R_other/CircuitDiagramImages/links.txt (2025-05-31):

Links for circuit diagram

https://www.pololu.com/product/2191 
https://learn.sparkfun.com/tutorials/how-to-use-a-breadboard/all 
https://www.circuitbasics.com/how-to-setup-and-program-rotary-encoders-on-the-arduino/ 
https://www.amazon.ca/SunFounder-Serial-Module-Display-Arduino/dp/B019K5X53O?th=1 
https://hub360.com.ng/product/tea5767-fm-radio-module/ 
https://store.fut-electronics.com/products/fm-radio-receiver-module-with-antenna-tea5767 
https://www.amazon.ca/dp/B07T5L5GY4 
https://www.freepik.com/psd/electricity 
https://www.amazon.ca/Arduino-Dual-axis-Joystick-Quality-Control/dp/B07Z453Y4H 
https://icontact-2.myshopify.com/products/2600mah-power-bank-green-210series

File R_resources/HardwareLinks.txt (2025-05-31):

MAIN HARDWARE:

Arduino UNO Microcontroller
Rotary Encoder with Button https://addison-electronique.com/en/iduino-rotary-encoder-module.html 
LCD Display that is I2C compatible 
Tuner Module 1 (FM only) with Antenna (TEA5767) : https://www.amazon.ca/dp/B074TC3VLN
Amplifier 1 (TDA7297) : https://www.amazon.ca/dp/B07T5L5GY4
Male-to-male Headphone Wire : https://www.amazon.ca/dp/B01L0YPVOY
New Speakers : https://www.amazon.ca/gp/product/B07G9ZMYMZ
Joystick : https://addison-electronique.com/en/5-pin-thumb-joystick-module-for-arduino.html 
Power Bank     OR     9V Battery     OR     Power from a Computer
Male-to-male Jumper Wires
Male-to-female Jumper Wires
Breadboard

HARDWARE NO LONGER NEEDED/NOT IN USE:

Tuner Module 2 (FM and AM) (TEF6686) : https://www.amazon.ca/dp/B0DXF17PTN
Amplifier 2 (PAM8403) : https://www.amazon.ca/dp/B075ZR6QNX
Rotary Potentiometer : https://www.amazon.ca/dp/B082FCRQS2
Old Speakers : https://www.amazon.ca/dp/B07BFTYY6L
Telescopic Antenna : https://www.amazon.ca/dp/B07SB58JMB
Simple Connector for 9V Battery : https://www.amazon.com/dp/B0002ZPFU8
Stereo Jack Socket Connector : https://www.amazon.ca/dp/B089W8P21R OR https://www.amazon.ca/dp/B093V39PVJ
Pitch Changer : https://www.amazon.ca/dp/B097YS5ZMQ
2.00-mm Headers : https://www.amazon.ca/dp/B09FSD82RB
2.54-mm Headers
Capacitors

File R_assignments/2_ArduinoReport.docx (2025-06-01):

James R. Di Re, Abdulrahman Kikia, Claudio Scione

May 31st, 2025

MakerSPACE Internship

# Arduino Radio - Final Report

## Introduction

In this report, we will detail the brainstorming, designing, coding and building of our Arduino internship project: an Arduino powered AM/FM radio. Over the course of the past three months, we have worked to put together a working radio while documenting the entire process to serve as an inspiration and a guide to anyone else who may want to embark on a similar project. Our goal when choosing this as our project was not only to improve our coding and debugging skills through a hands-on approach, but also to gain an understanding of radio waves, audio processing, and speakers. All this, in addition to enjoying the satisfaction of listening to music through a device we made from scratch.

## Project Description

### Objective

The goal of this project was to build a working AM/FM radio, using the Arduino Uno as the motherboard and the Arduino IDE to write the code. We aimed to not only be able to play music through speakers, but as display information about the frequency and station on a digital display. Finally, we wanted to design and build a casing to insert all the hardware into that was practical and portable. While this was the base goal of this project, we hoped to add as many features as possible to the radio within the time frame we had to complete this project. We hoped to add a function to set pre-set radio stations that you could choose and change as you wished, shortwave compatibility, radio station scanning and even Bluetooth connectivity.

### Inspiration

It was James who originally came up with the idea of making a radio using Arduino. He had watched a few videos on YouTube of people building using Arduino to make working radios. The videos he watched used FM only radio modules, and only detailed the wiring process. We decided it would be interesting to expand on those projects James had seen online to make a radio with more features and a case to enclose it in. After some research on the Arduino forums and other build project sites, we saw other examples of radios, each with their own unique construction and design. That made us realize that this was something we could realistically build and design on our own in the months we had to work on this project.

### Design and Planning

For the design, we wanted to build a radio that is reminiscent of old-school radio devices. We wanted to use knobs instead of buttons. We also wanted it to be unique with mismatching sizes for the different buttons, all while having some symmetry. We shared different sketches of the design and some concept 3D renders to see where our imagination could go. In the end, we couldn’t settle on a specific design until we got all parts working and tested.

Designing a case to house all the parts proved to be a challenge. The setup out of the box functioned well, but was fragile in the initial phases. The speaker wires kept disconnecting from the antenna with the slightest movement. Whenever we would tighten the screws to hold the wires in place, the wires would go out, or the speaker could stop playing. There were also pieces that had to be mounted to the front, so that the user can interact with the radio as intended. We made a prototype using cardboard to see how the pieces would go together. The speakers were problematic as they don’t screw holes to mount them in place. Their wires also interfered with the screen if the positioning wasn’t optimal. So we had to figure out the perfect position for them and add a shelf that comes out of the sides, such that they sit on top of them.

The screen, antenna and rotary encoder have screw holes so mounting them wasn’t an issue. However, using the battery was our real issue. The connector that the battery uses is very stiff and doesn’t come easily out of its terminals. So removing the battery wasn’t a feasible option to cut the circuit. After trying different options, we ended up using a power bank as our power source, as it can be easily removed and charged when needed. For the arduino board, we added holes for accessing its USB and power ports when mounted.

Initially the idea was to have the six faces of the box snap into each other through a connector that was meant to hold them by pressure. However, as the pieces are small and would break with high pressure, we had to change the design into a box, of which the rear pieces slide out for quick access. The breadboard sits in the bottom and connects to the other pieces. The speaker drivers and the amplifier sit on extruded platforms made for them, while other pieces are mounted to the walls of the chassis. The result is a radio that is fairly portable, and is comparable to other radios of its kind in size.

## Implementation

### Hardware Setup

- Arduino Uno microcontroller
- Rotary encoder with button - for frequency tuning
- LCD display that is I²C compatible - for displaying radio data
- TEA5767 FM radio module with antenna - for receiving radio signals
- TDA7297 amplifier - for amplifying the audio signal coming from the radio module and for allowing volume control
- Male-to-male headphone wire - for sending the audio signal from the radio module to the amplifier
- Speakers
- Joystick - for choosing between different preset stations (up, down, left, right = 4 presets)
- Power source: power bank OR 9V battery OR power from a computer
- Male-to-male jumper wires
- Male-to-female jumper wires
- Breadboard

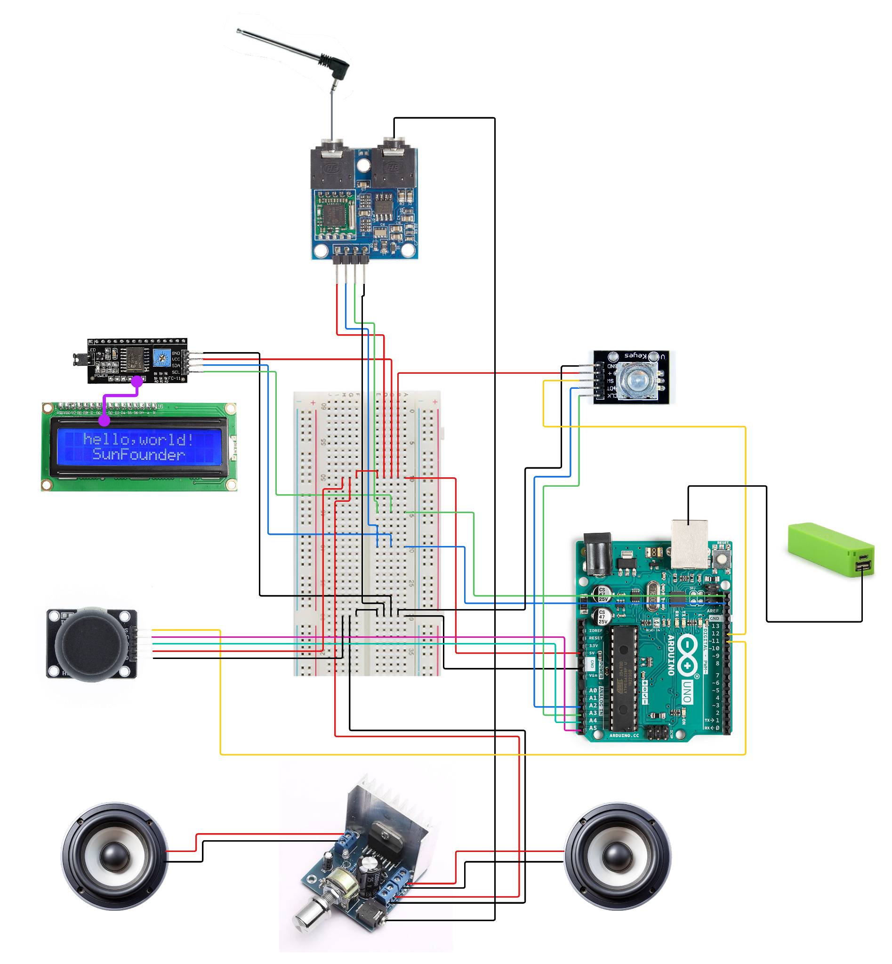
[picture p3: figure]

### Software Development

Firstly, James already had C++ knowledge from a tutorial series he had watched on YouTube a few years ago, so because of that, it was a lot easier for him to write code for the project compared to someone just starting out. However, this was still his first time putting that knowledge into real practice. James recommended to the other group members that they watch some videos from the tutorial series too.

The features in the code were at first programmed in the Arduino IDE, and were added gradually (for example, first the code for the rotary encoder and LCD display were added, then the code for the radio module, then the code for the joystick, then the code for preset saving, etc.). The code was always kept in a maintainable condition that was simple to expand upon. This was a top priority, as James knew from past projects that untidy code gets exponentially hard to maintain. Eventually, even though the code was kept organized, it was still overwhelming to keep all the functionality in one file. Thus, it was separated into six separate files: the main cpp file, a main header file, a class for managing radio state, a class for handling input, a class for handling the LCD display, and a class for handling the radio module. Later on in development, this proved to be a great choice, as each of these files grew in size. Looking back, it would not have been feasible to keep everything in a single file.

However, separating the code into different files didn’t come without its own problems. For one thing, there were many bugs that got introduced as a result, and all of them were isolated to being issues regarding C++’s copying of objects in unexpected areas. As a result, in fixing these bugs, the team grew more familiar with C++’s copying conventions, and became more aware of when it was appropriate to use pointers (*) or references (&).

Eventually, the entirety of the code was moved to Visual Studio Code. This provided many advantages over the Arduino IDE. For one thing, VS Code allowed for easy integration with version control software such as Git and GitHub. Also, it underlines compilation errors in real-time, a feature which the Arduino IDE lacks entirely.

### Sensor Documentation

- Antenna

The antenna picks FM signals and transmits them into the amplifier.

- Amplifier

The amplifier picks the sounds signal (from the antenna) and transmits them into the speakers. It also has a potentiometer that controls the power given to the speaker (the volume coming out of them).

- Rotary Encoder

The rotary encoder helps with navigating radio stations. Each step in the rotation gives the arduino board a signal to either increase or decrease the frequency picked from the antenna by 0.2, which is by how much FM signal changes.

- Joystick

The joystick has two potentiometers for dual axis rotation. It can detect the rotation of the stick in eight directions and in our case is the optimal way to select and tune-in on presets.

## Results

## Analysis

## Discussion and Conclusion

## References

## Acknowledgements

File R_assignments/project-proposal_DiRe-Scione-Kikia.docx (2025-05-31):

AM and FM Radio

Team Members: James R. Di Re, Claudio Scione, Abdulrahman Kikia

The AM and FM radio will allow its users to listen to local radio stations so that they may stay informed on local news and enjoy music. It is meant to be compact so that users can bring it with them anywhere. The radio functions using a radio receiver module that is communicated with by an Arduino UNO, which then sends the audio to a speaker so that users can hear it. If time permits, the radio will also be designed to support preset stations and radio station scanning, and possibly Bluetooth playback. The goal of this project is to gain an understanding of radio waves, audio processing, and speakers, in addition to having a functional radio that can be used anytime.

Hardware:

- Arduino Uno
- Sensors and Modules:
  - AM/FM radio receiver module (e.g. Si4732) for receiving radio signals and tuning to specific frequencies
  - Amplifier (e.g. maybe the TDA7297?)
  - Switch for on/off functionality
  - Potentiometer knob for volume control
  - Rotary encoder knob with button for frequency tuning and for toggling between AM and FM
- Other Components:
  - Jumper wires and breadboard
  - Speaker
  - LCD display to show current radio station and other information
  - Battery or power supply
  - Telescopic antenna
- Future Expansion:
  - Rotary switch (knob that snaps to specific positions) to change between radio station presets
  - Button to set new radio station presets
  - Bluetooth module to play music from one’s phone through the radio speaker
  - Perhaps an analog VU meter to show how loud the audio is at any given time, as a nice visual

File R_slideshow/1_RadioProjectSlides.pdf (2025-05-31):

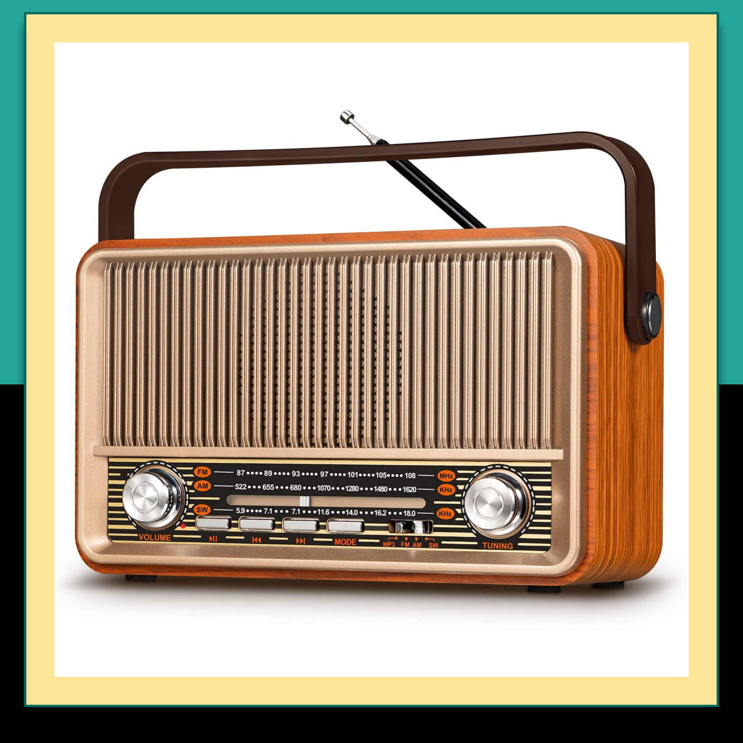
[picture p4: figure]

## Arduino FM Radio

James R. Di Re | Abdulrahman Kikia | Claudio Scione

## Initial Objectives

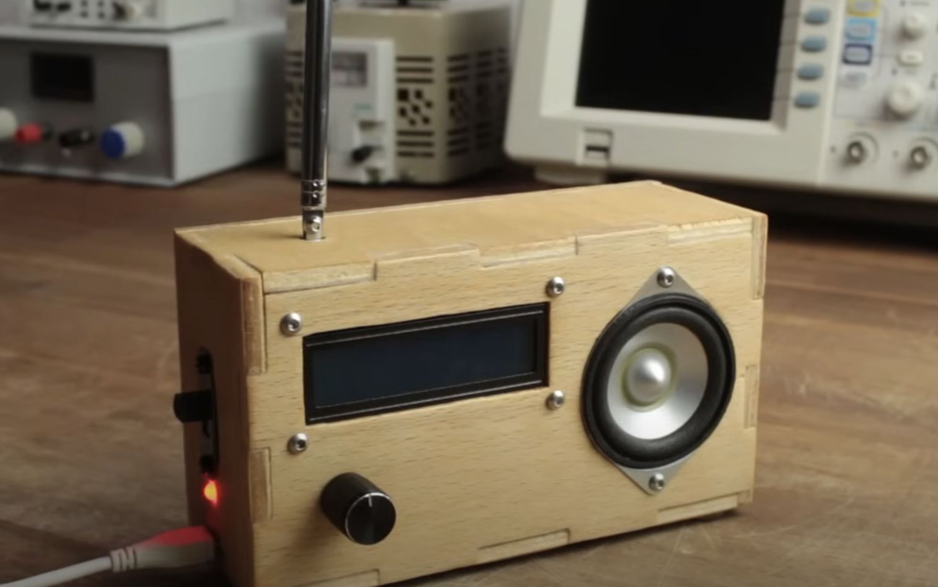
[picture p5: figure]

- Must be portable —------->
- Should support different bands of reception (FM, AM, Shortwave, etc.)
- Display information on an LCD
- Support presets (ex. 1, 2, 3, 4, 5)
- RDS (prints current song)
- Scanning
- Bluetooth compatibility (i.e. play audio from your phone)

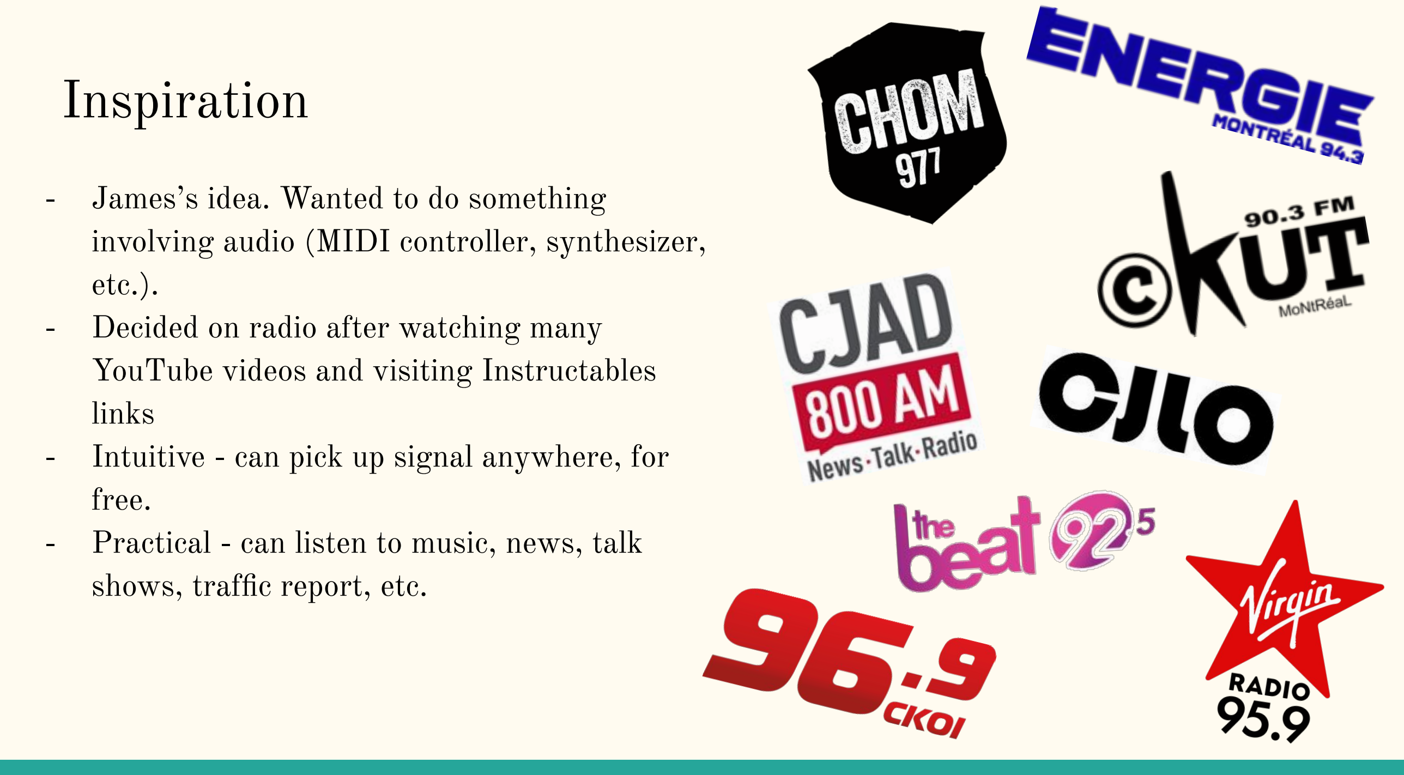
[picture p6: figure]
Inspiration; - James’s idea. Wanted to do something involving audio (MIDI controller, synthesizer, etc.). - Decided on radio after watching many YouTube videos and visiting Instructables links; free.; shows, traffic report, etc.

- Intuitive - can pick up signal anywhere, for
- Practical - can listen to music, news, talk

Put some images of inspiration videos

## Design and Planning

- Initial radio sketches
- Problems
- Speaker wires kept disconnecting
- Speakers hard to mount on box (no screw holes)
- Adding features gradually (first rotary encoder, then LCD, then radio module, then amplifier and speaker)
- Cardboard prototype

## Hardware Setup

List hardware

Put some of the in-progress images here

Put some diagram here for the circuit

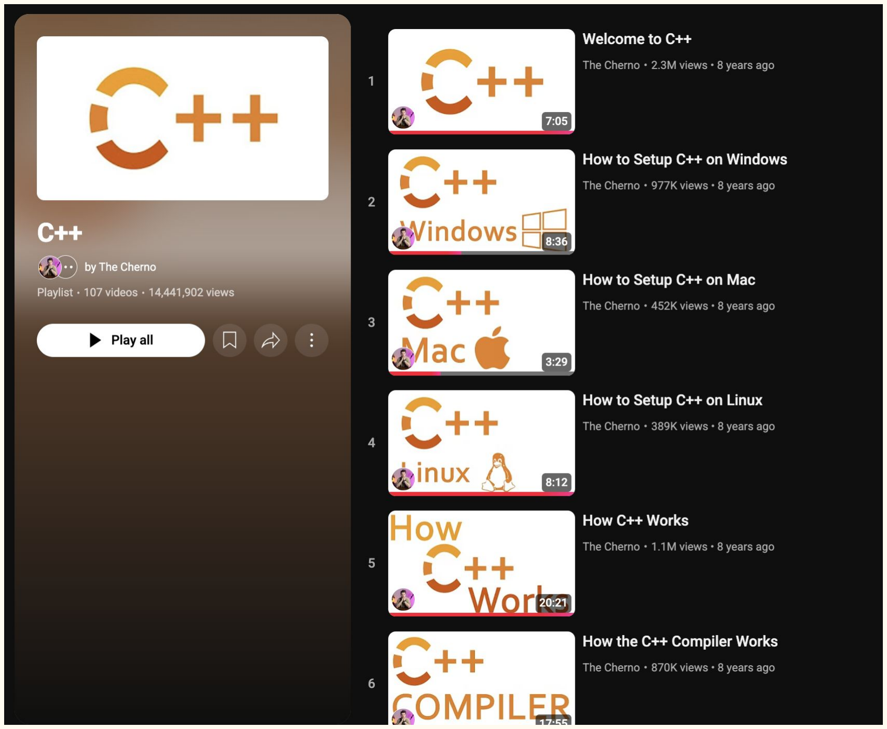
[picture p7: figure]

- Already had some prior knowledge of CPP from this tutorial series —------------>
- Made writing the radio code simpler
- However, this was the first time putting that knowledge into practice

## <!-- Code -->

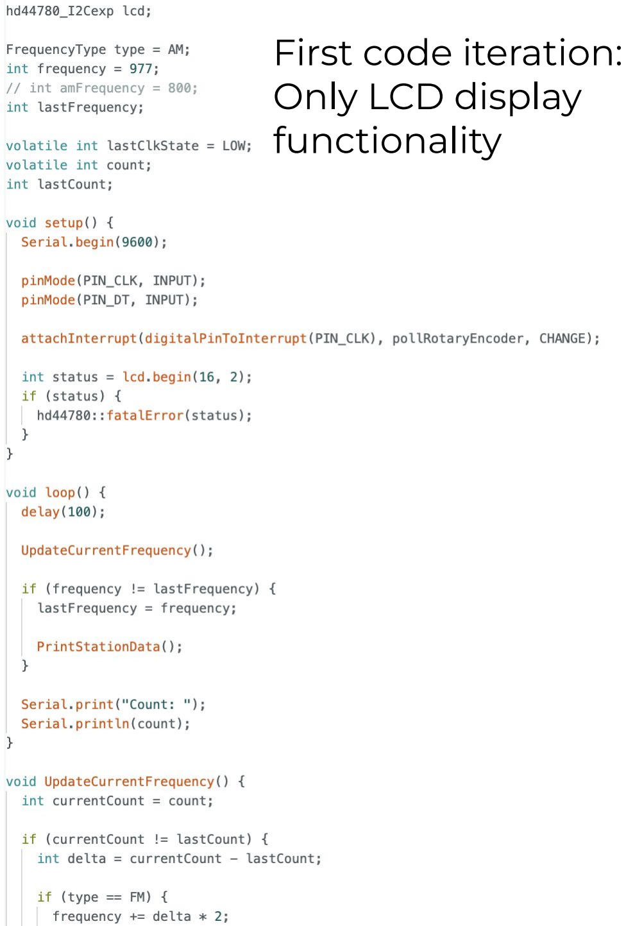
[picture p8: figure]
First code iteration: Only LCD display functionality

### Later code iteration: separated into six files! Reasons: Scalability, more control, more organized

main.cpp -

Entry point of the program. Contains setup() and loop() functions
RadioHeaders.h -

Header file for all the following classes. Contains variables and function declarations. All other files #include this
class RadioHandler { } -

General class for managing many of the properties of the radio. Manages current station, states, etc
class RadioInput { } -

Handles functionality for the rotary encoder and the joystick
class RadioDisplay { } -

Handles everything to do with displaying information on the LCD screen, including methods for printing text

class RadioModule { } -

Handles communicating with the radio module and tuning to stations.

## The switch to Visual Studio Code

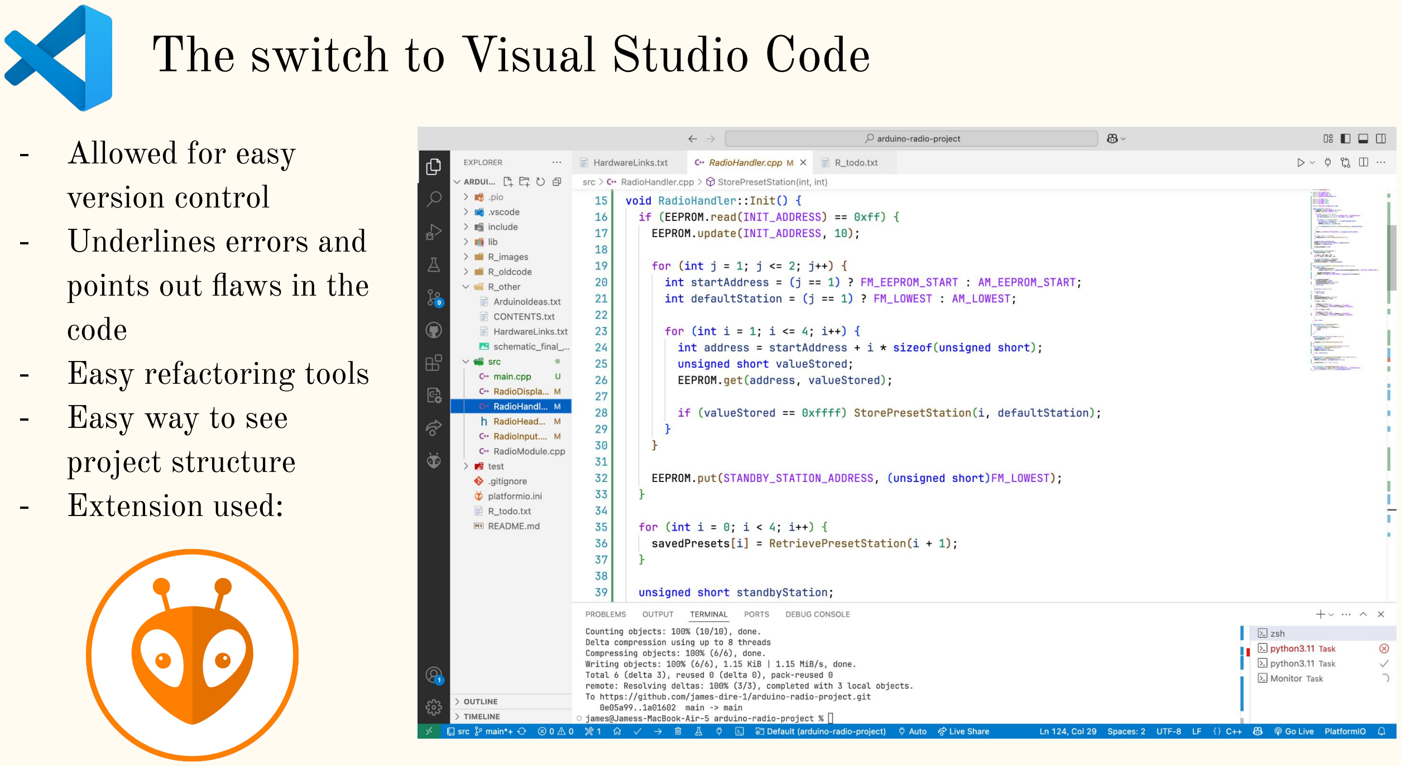
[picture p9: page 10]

- Allowed for easy
version control
- Underlines errors and
points out flaws in the
code
- Easy refactoring tools
- Easy way to see
project structure
- Extension used:

## Libraries Used

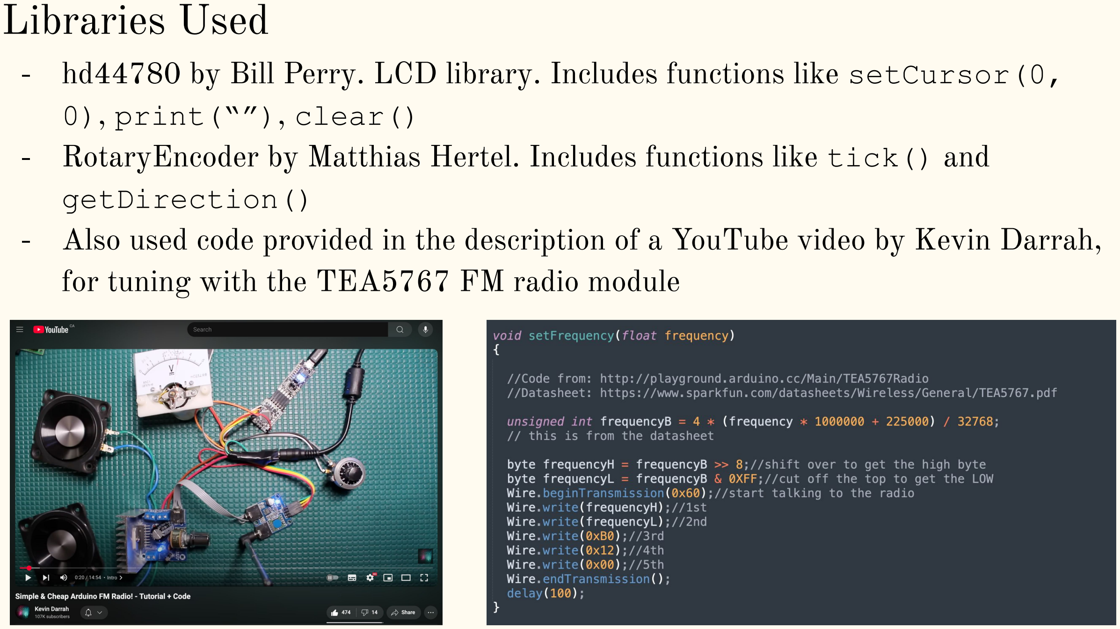
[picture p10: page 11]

- hd44780 by Bill Perry. LCD library. Includes functions like setCursor(0,
0), print(“”), clear()
- RotaryEncoder by Matthias Hertel. Includes functions like tick() and

getDirection()
- Also used code provided in the description of a YouTube video by Kevin Darrah, for tuning with the TEA5767 FM radio module

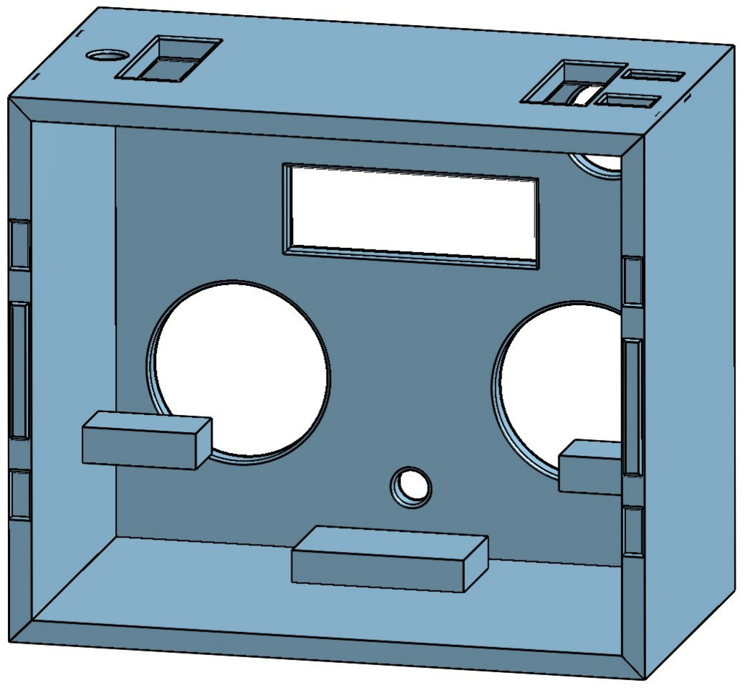
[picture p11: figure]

## Initial Design for the box

Had to be changed to make the assembly possible

Put the results/successes here !!!

Persisting Issues:
- Interference noise caused by the LCD screen updating and joystick movement
- Joystick messing up the 1²C communication lines. Causes code freeze ups. (Isolated problem by removing joystick code and changing station every 1 second)

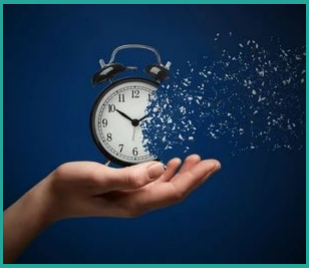
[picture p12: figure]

Lacking Features:
- Only FM support. Plans to try out different (more low-level, complicated) radio module, but no time
- No Bluetooth connectivity
- No RDS, scanning, bluetooth support

Discussion and conclusion ?

https://www.shutterstock.com/search/time-running-out

https://en.m.wikipedia.org/wiki/File:Visual_Studio_Code_1.35_icon.svg

https://commons.wikimedia.org/wiki/File:PlatformIO_logo.svg

https://www.amazon.ca/PRUNUS-J120-Shortwave-Rechargeable-Playing%E3%80%902023/dp/B0BMT86PBV

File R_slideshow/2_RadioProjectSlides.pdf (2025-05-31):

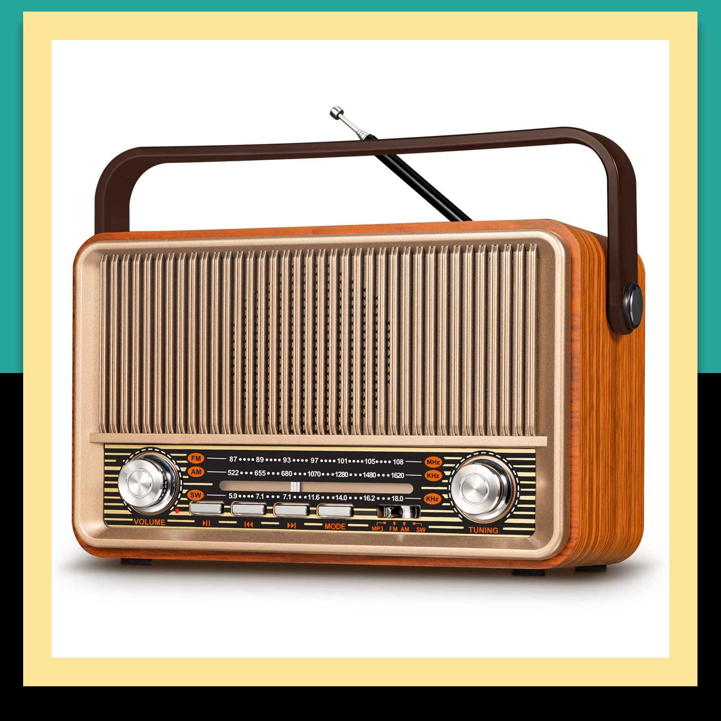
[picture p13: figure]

## Arduino FM Radio

James R. Di Re | Abdulrahman Kikia | Claudio Scione

## Initial Objectives


- Must be portable —------->
- Should support different bands of reception (FM, AM, Shortwave, etc.)
- Display information on an LCD
- Support presets (ex. 1, 2, 3, 4, 5)
- RDS (prints current song)
- Scanning
- Bluetooth compatibility (i.e. play audio from your phone)

Abdulrahman

## Inspiration

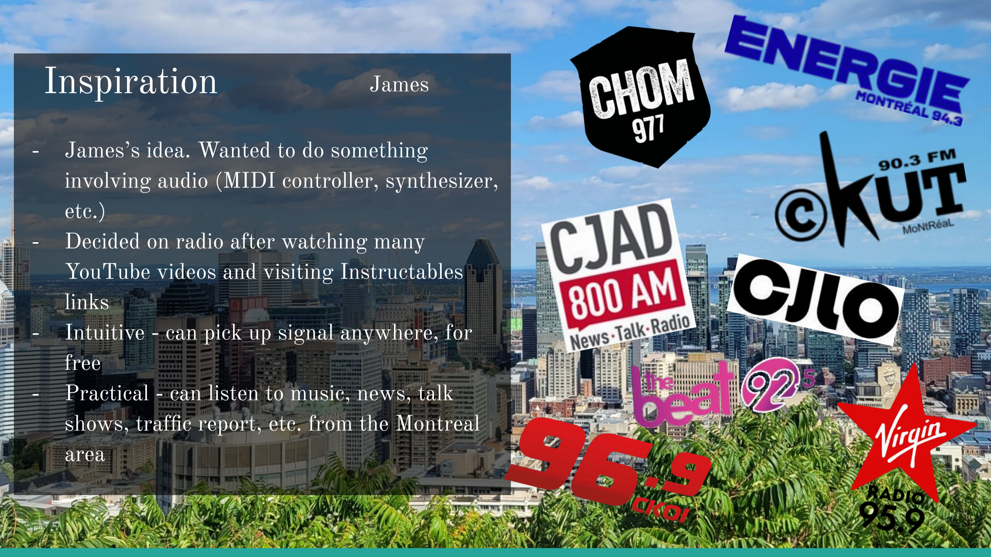
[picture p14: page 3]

- James’s idea. Wanted to do something involving audio (MIDI controller, synthesizer, etc.)
- Decided on radio after watching many YouTube videos and visiting Instructables links
- Intuitive - can pick up signal anywhere, for free
- Practical - can listen to music, news, talk shows, traffic report, etc. from the Montreal area

James

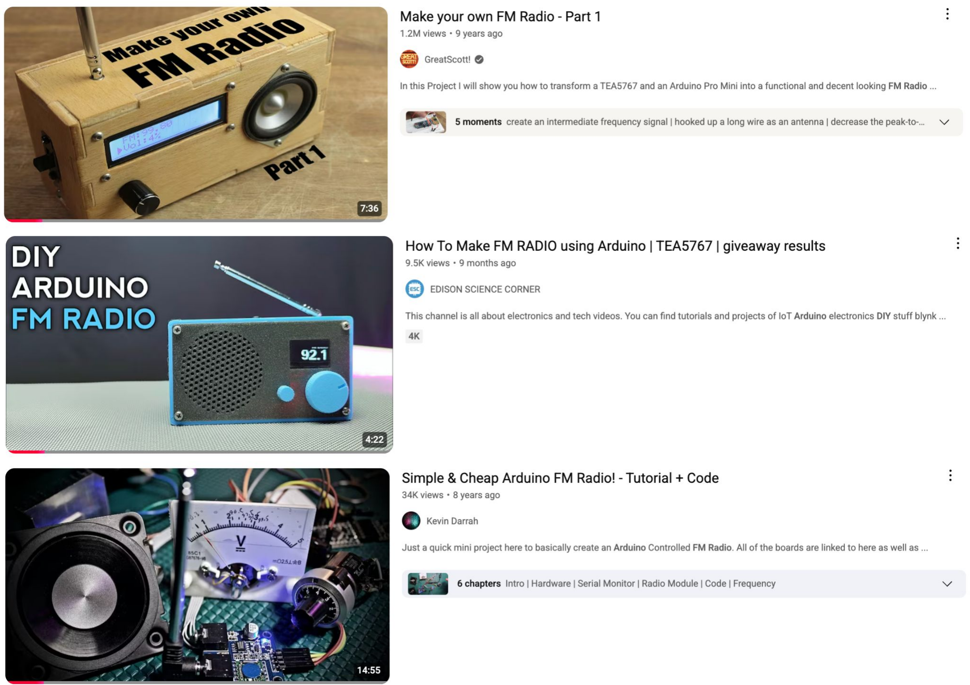
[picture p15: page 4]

## Design and Planning

- Initial radio sketches
- Problems
- Speaker wires kept disconnecting
- Speakers hard to mount on box (no screw holes)
- Adding features gradually (first rotary encoder, then LCD, then radio module, then amplifier and speaker)
- Cardboard prototype

## Hardware Setup

- Arduino UNO Microcontroller
- Rotary Encoder (tuner knob)
- LCD Display (I²C)
- TEA5767 FM Radio Module
- TDA7297 Amplifier
- Speakers
- Joystick
- Power Source
- Headphone Wire, Jumper Wires, Breadboard

Abdulrahman

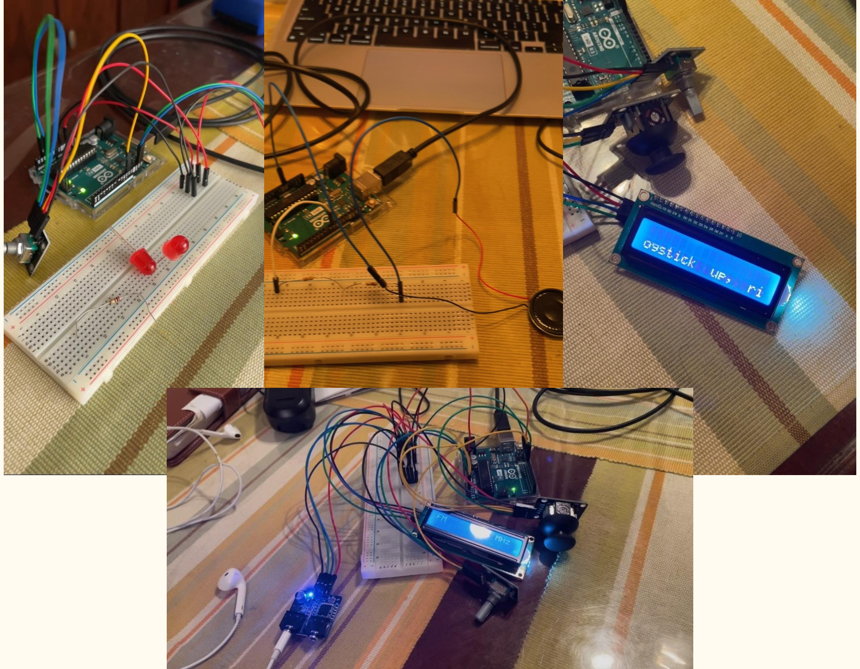
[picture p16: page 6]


- Already had some prior knowledge of CPP from this tutorial series —------------>
- Made writing the radio code simpler
- However, this was the first time putting that knowledge into practice

## <!-- Code -->

James

First code iteration: Only LCD display functionality

### Later code iteration: separated into six files! Reasons: Scalability, more control, more organized

main.cpp -

Entry point of the program. Contains setup() and loop() functions
RadioHeaders.h -

Header file for all the following classes. Contains variables and function declarations. All other files #include this
class RadioHandler { } -

General class for managing many of the properties of the radio. Manages current station, states, etc
class RadioInput { } -

Handles functionality for the rotary encoder and the joystick
class RadioDisplay { } -

Handles everything to do with displaying information on the LCD screen, including methods for printing text

class RadioModule { } -

Handles communicating with the radio module and tuning to stations.

## The switch to Visual Studio Code


- Allowed for easy
version control
- Underlines errors and
points out flaws in the
code
- Easy refactoring tools
- Easy way to see
project structure
- Extension used:

## Libraries Used


- hd44780 by Bill Perry. LCD library. Includes functions like setCursor(0,
0), print(“”), clear()
- RotaryEncoder by Matthias Hertel. Includes functions like tick() and

getDirection()
- Also used code provided in the description of a YouTube video by Kevin Darrah, for tuning with the TEA5767 FM radio module


## Initial Design for the box

Had to be changed to make the assembly possible

Abdulrahman

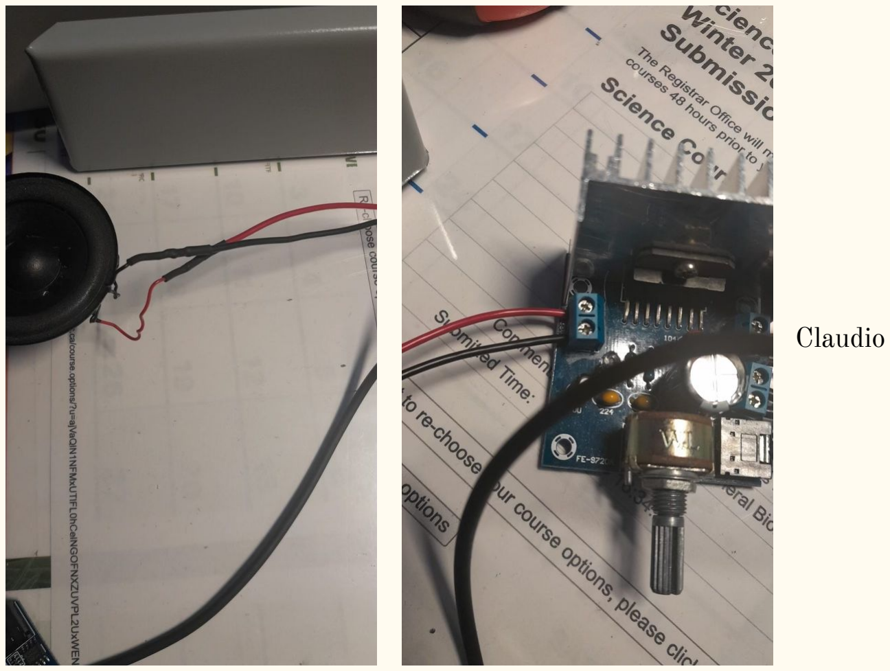
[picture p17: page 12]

Claudio

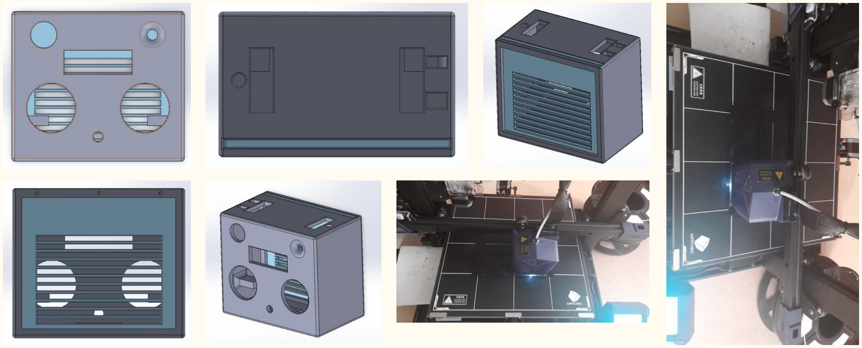
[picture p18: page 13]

## Results/Successes

- Functional FM tuning with knob
- Informative display that shows band, station, preset
- Tuning to presets (although some problems)
- Overwriting presets
- Decent audio quality
- Organized code that was easy to maintain

Claudio

Persisting Issues:
- Interference noise caused by the LCD screen updating and joystick movement
- Joystick messing up the 1²C communication lines. Causes code freeze ups. (Isolated problem by removing joystick code and changing station every 1 second)
- Volume knob can’t be turned all the way


Lacking Features:
- Only FM support. Plans to try out different (more low-level, complicated) radio module, but no time
- No Bluetooth connectivity
- No RDS, scanning, bluetooth support

James

## What We Learnt

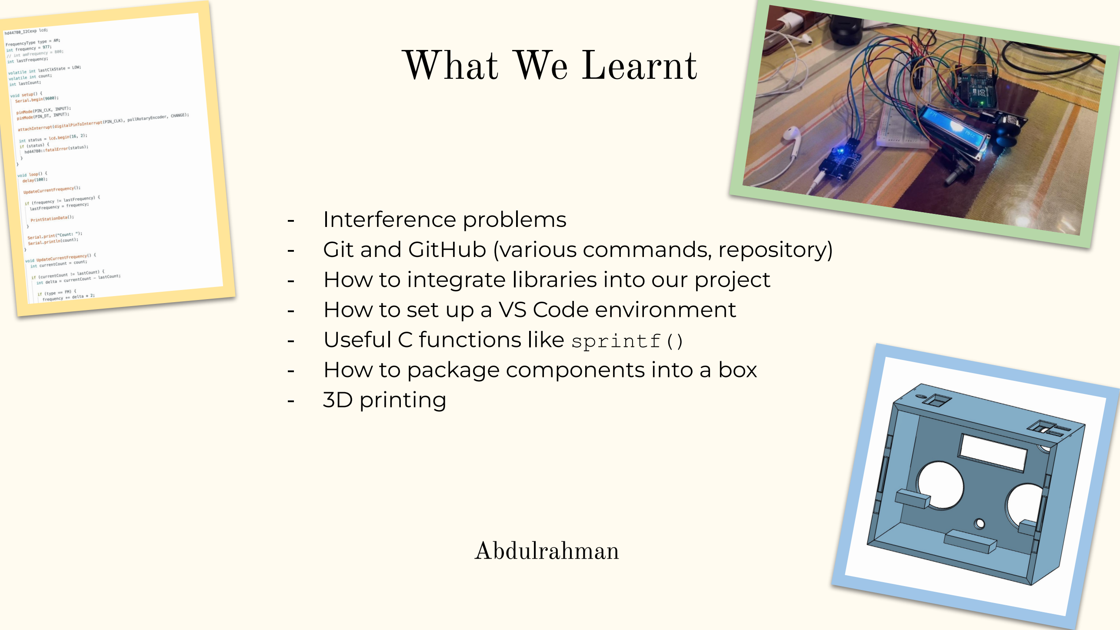
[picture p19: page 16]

- Interference problems
- Git and GitHub (various commands, repository)
- How to integrate libraries into our project
- How to set up a VS Code environment
- Useful C functions like sprintf()
- How to package components into a box
- 3D printing

Abdulrahman https://www.shutterstock.com/search/time-running-out

https://en.m.wikipedia.org/wiki/File:Visual_Studio_Code_1.35_icon.svg

https://commons.wikimedia.org/wiki/File:PlatformIO_logo.svg

https://www.amazon.ca/PRUNUS-J120-Shortwave-Rechargeable-Playing%E3%80%902023/dp/B0BMT86PBV

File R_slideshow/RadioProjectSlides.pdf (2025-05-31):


## Arduino FM Radio

James R. Di Re | Abdulrahman Kikia | Claudio Scione

## Initial Objectives


- Must be portable —------->
- Should support different bands of reception (FM, AM, Shortwave, etc.)
- Display information on an LCD
- Support presets (ex. 1, 2, 3, 4, 5)
- RDS (prints current song)
- Scanning
- Bluetooth compatibility (i.e. play audio from your phone)

Abdulrahman

## Inspiration


- James’s idea. Wanted to do something involving audio (MIDI controller, synthesizer, etc.)
- Decided on radio after watching many YouTube videos and visiting Instructables links
- Intuitive - can pick up signal anywhere, for free
- Practical - can listen to music, news, talk shows, traffic report, etc. from the Montreal area

James


## Design and Planning

- Initial radio sketches
- Problems
- Speaker wires kept disconnecting
- Speakers hard to mount on box (no screw holes)
- Adding features gradually (first rotary encoder, then LCD, then radio module, then amplifier and speaker)
- Cardboard prototype

## Hardware Setup

- Arduino UNO Microcontroller
- Rotary Encoder (tuner knob)
- LCD Display (I²C)
- TEA5767 FM Radio Module
- TDA7297 Amplifier
- Speakers
- Joystick
- Power Source
- Headphone Wire, Jumper Wires, Breadboard

Abdulrahman



- Already had some prior knowledge of CPP from this tutorial series —------------->
- Made writing the radio code simpler
- However, this was the first time putting that knowledge into practice

## <!-- Code -->

James

First code iteration: Only LCD display functionality

### Later code iteration: separated into six files! Reasons: Scalability, more control, more organized

main.cpp -

Entry point of the program. Contains setup() and loop() functions
RadioHeaders.h -

Header file for all the following classes. Contains variables and function declarations. All other files #include this
class RadioHandler { } -

General class for managing many of the properties of the radio. Manages current station, states, etc
class RadioInput { } -

Handles functionality for the rotary encoder and the joystick
class RadioDisplay { } -

Handles everything to do with displaying information on the LCD screen, including methods for printing text

class RadioModule { } -

Handles communicating with the radio module and tuning to stations.

## The switch to Visual Studio Code


- Allowed for easy
version control
- Underlines errors and
points out flaws in the
code
- Easy refactoring tools
- Easy way to see
project structure
- Extension used:

## Libraries Used


- hd44780 by Bill Perry. LCD library. Includes functions like setCursor(0,
0), print(“”), clear()
- RotaryEncoder by Matthias Hertel. Includes functions like tick() and

getDirection()
- Also used code provided in the description of a YouTube video by Kevin Darrah, for tuning with the TEA5767 FM radio module


## Initial Design for the box

Had to be changed to make the assembly possible

Abdulrahman


Claudio

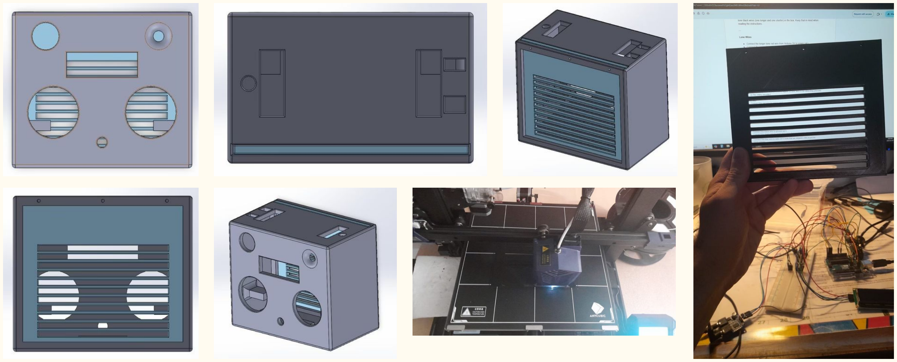
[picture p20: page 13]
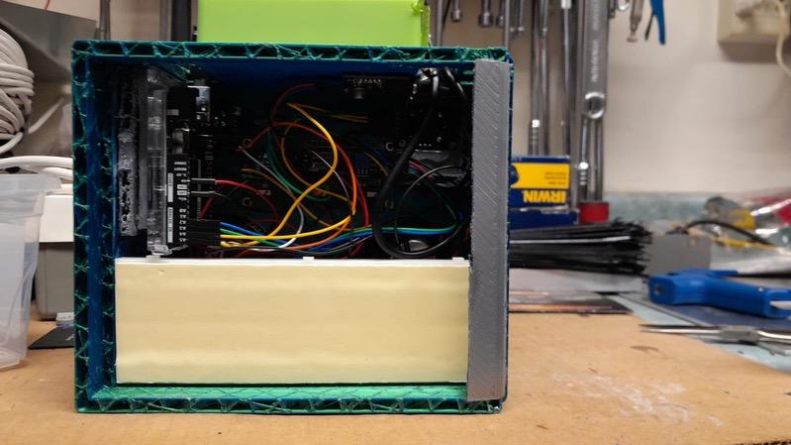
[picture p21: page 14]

## Results/Successes

- Functional FM tuning with knob
- Informative display that shows band, station, preset
- Tuning to presets (although some problems)
- Overwriting presets
- Decent audio quality
- Organized code that was easy to maintain

Claudio

Persisting Issues:
- Interference noise caused by the LCD screen updating and joystick movement
- Joystick messing up the 1²C communication lines. Causes code freeze ups. (Isolated problem by removing joystick code and changing station every 1 second)
- Volume knob can’t be turned all the way


Lacking Features:
- Only FM support. Plans to try out different (more low-level, complicated) radio module, but no time
- No Bluetooth connectivity
- No RDS, scanning, bluetooth support

James

## What We Learnt

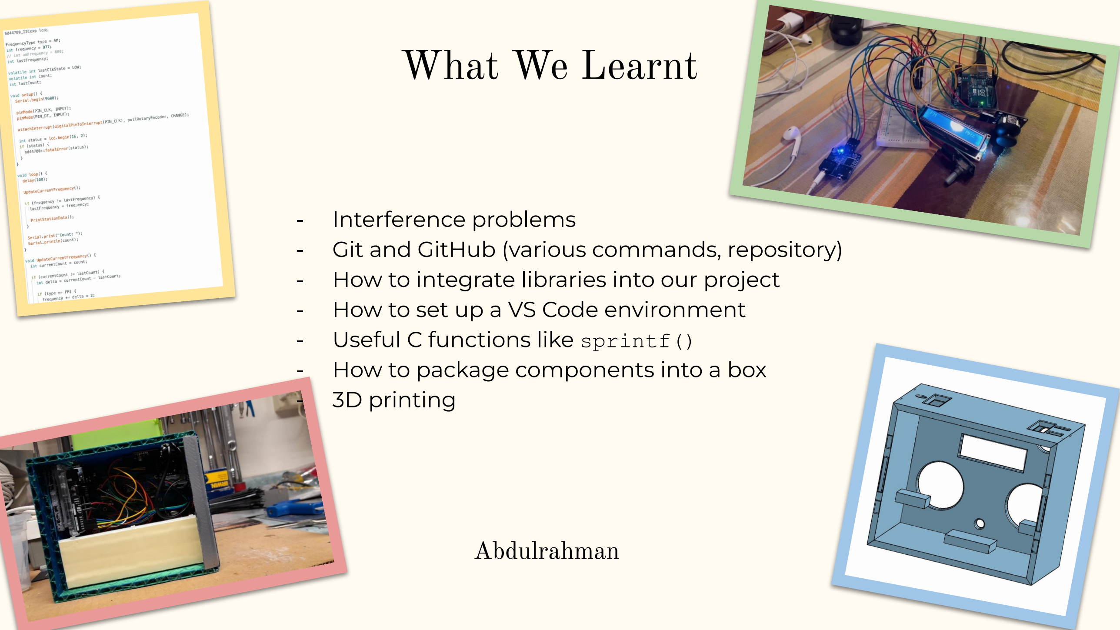
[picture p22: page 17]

- Interference problems
- Git and GitHub (various commands, repository)
- How to integrate libraries into our project
- How to set up a VS Code environment
- Useful C functions like sprintf()
- How to package components into a box
- 3D printing

Abdulrahman https://www.shutterstock.com/search/time-running-out

https://en.m.wikipedia.org/wiki/File:Visual_Studio_Code_1.35_icon.svg

https://commons.wikimedia.org/wiki/File:PlatformIO_logo.svg

https://www.amazon.ca/PRUNUS-J120-Shortwave-Rechargeable-Playing%E3%80%902023/dp/B0BMT86PBV

https://en.wikipedia.org/wiki/Montreal

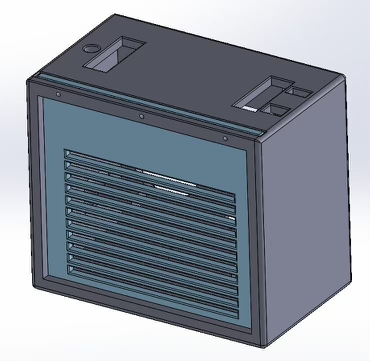
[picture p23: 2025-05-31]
R_other/SlideshowImages/9f3cc09c-55b2-42f0-a930-a709e449bb0a.png

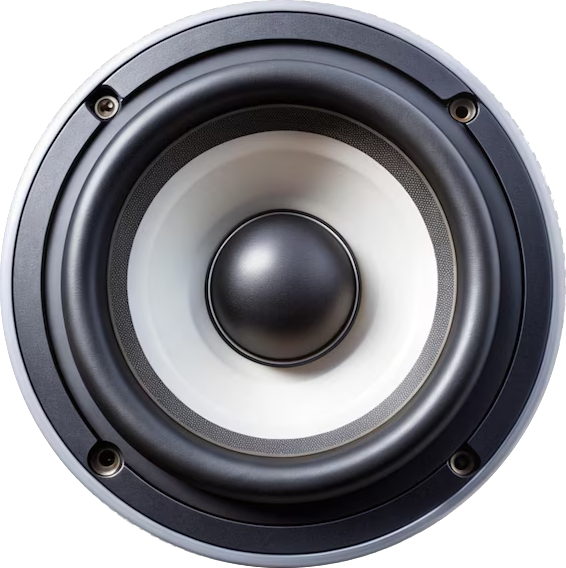
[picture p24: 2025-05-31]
R_other/CircuitDiagramImages/close-up-sleek-black-speaker-top-view-with-transparent-background_1046662-76241 copy.png

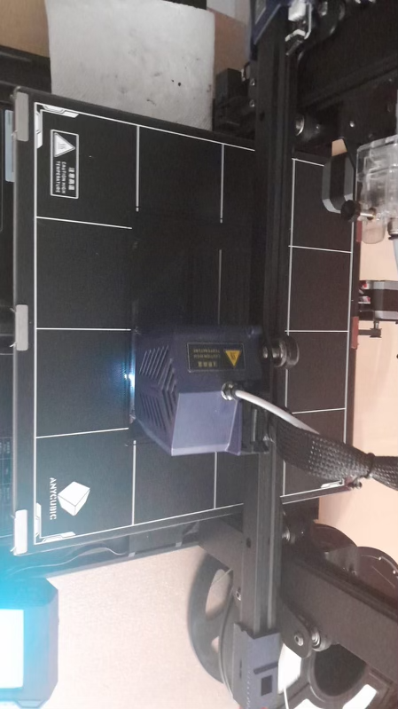
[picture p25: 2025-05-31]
R_other/SlideshowImages/44c77861-3a65-43ae-af4b-c7ee202eec60.png

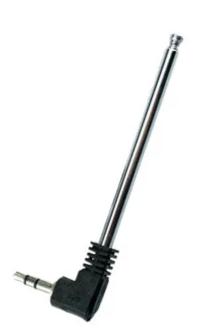
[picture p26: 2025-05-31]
R_other/CircuitDiagramImages/TEA5767_fm_radio_module copy.png

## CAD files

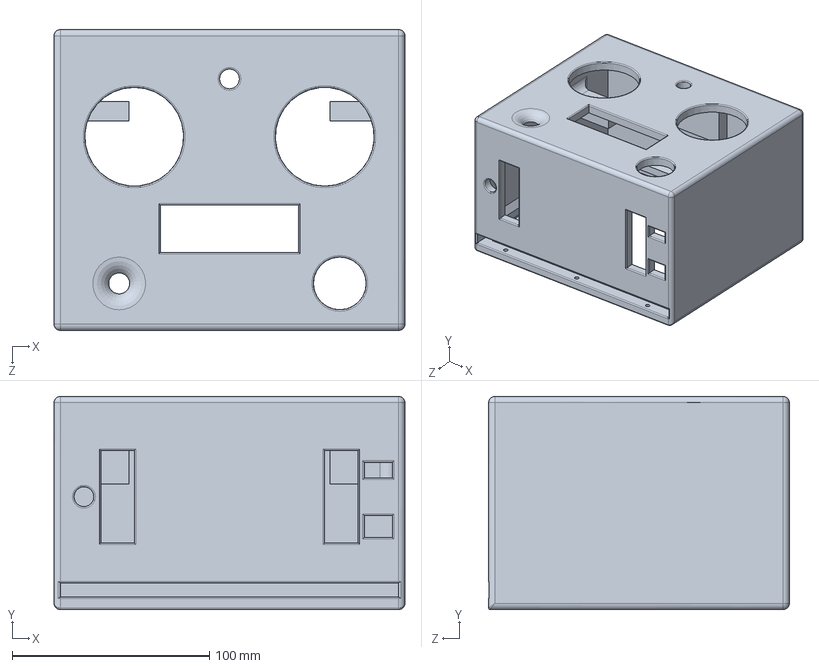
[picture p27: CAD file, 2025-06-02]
R_models/Main_box_assembly_part.SLDPRT
177.8 x 107.9 x 152.4 mm

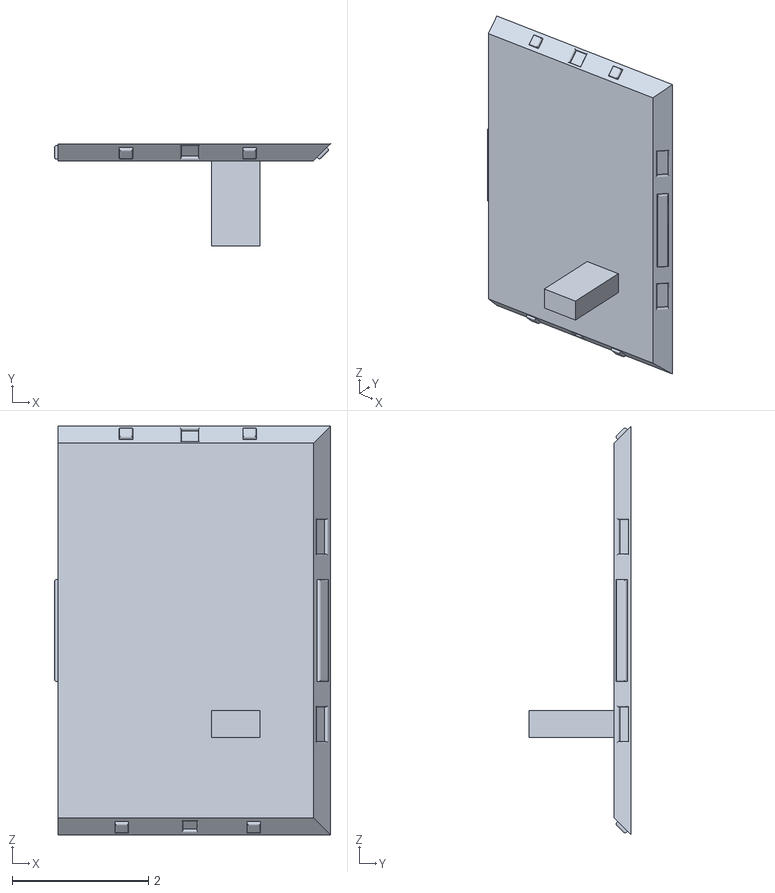
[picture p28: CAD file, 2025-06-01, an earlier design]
R_models/OldShortSideRight.stl
4.05 x 1.50 x 6.00

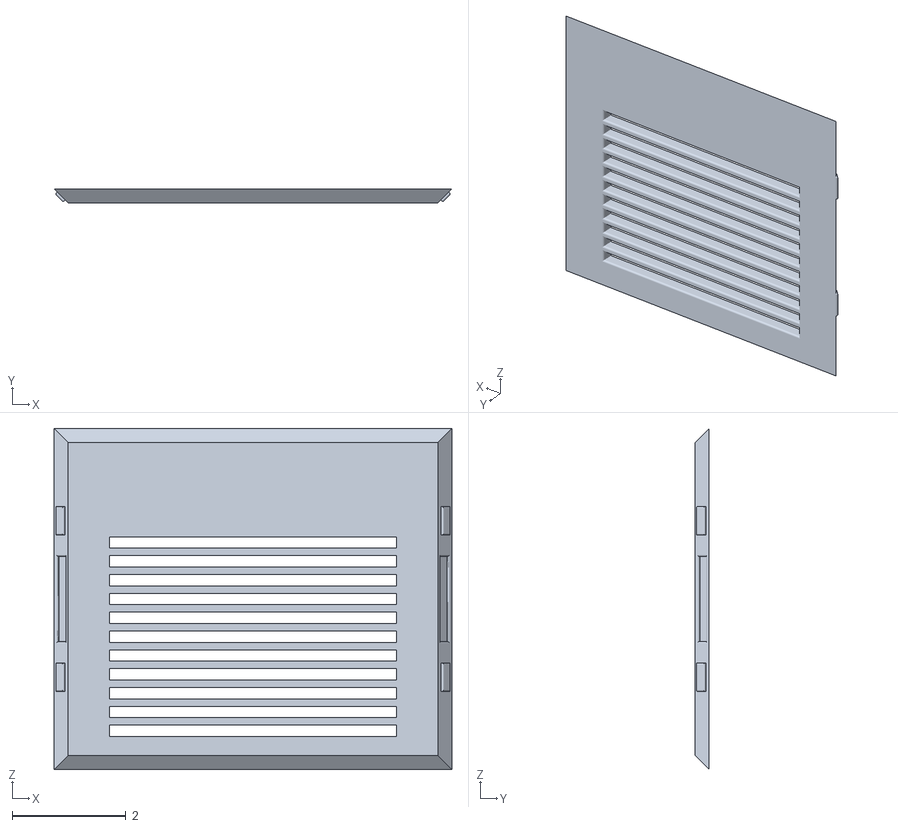
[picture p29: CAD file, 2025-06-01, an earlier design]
R_models/OldLongSideBack.stl
7.00 x 0.25 x 6.00

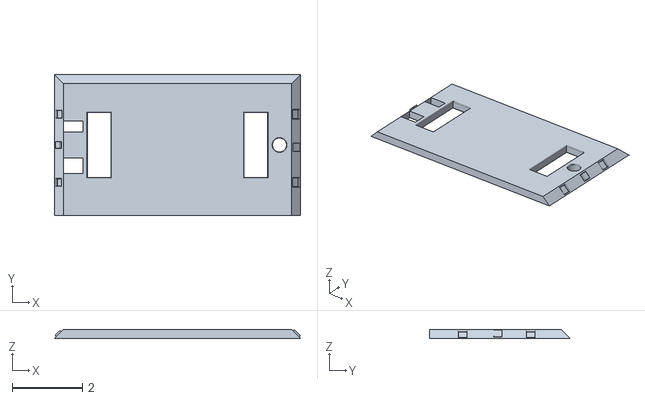
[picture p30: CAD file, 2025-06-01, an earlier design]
R_models/OldTop.stl
7.00 x 4.00 x 0.25

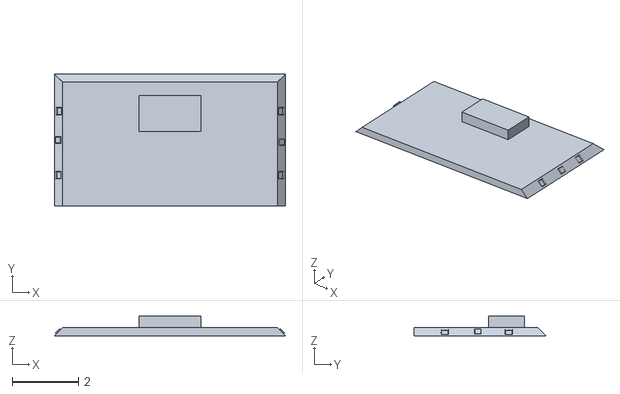
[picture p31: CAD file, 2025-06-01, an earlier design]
R_models/OldBase.stl
7.00 x 4.00 x 0.604

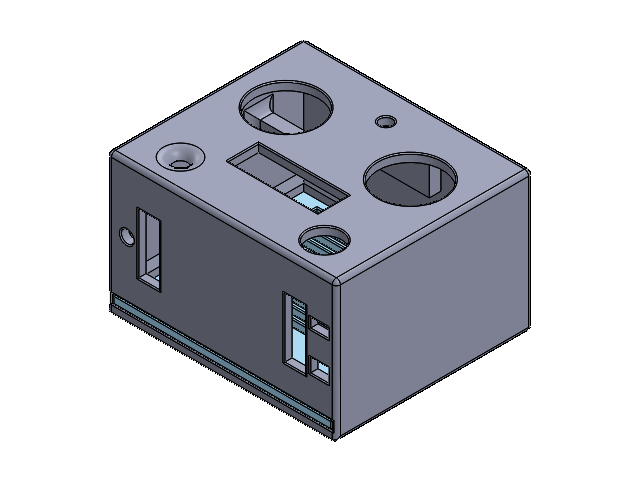
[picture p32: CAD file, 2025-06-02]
R_models/radio_case_assembly.SLDASM
Long Side
Main box assembly part

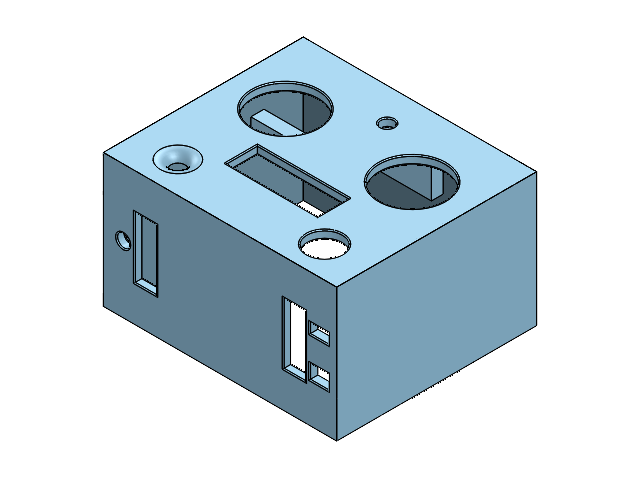
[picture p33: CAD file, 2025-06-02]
R_models/Main_box_assembly.SLDASM
Base
Short Side (Left)
Short Side (Right)
Top
With interface

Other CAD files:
R_models/OldShortSideLeft.stl
R_models/Main_box_assembly_part.STL

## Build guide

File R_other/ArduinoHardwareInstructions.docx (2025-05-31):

Arduino Hardware Instructions

Before I begin explaining the connections, let’s establish what I mean when I say power rail, ground rail, clock rail, and data rail. Power rail is row 10 on the breadboard. Clock rail is row 15. Data rail is row 20. Ground rail is row 30. That is how I’ve always been connecting the hardware up until this point, but using any rail is fine, and it could be necessary to change the rail to make wires work well in the box.

Also, wires in the rails are color coded. Power is red, ground is black, clock is green, data is blue. This will make it easier to connect things.

Also, all the wires necessary to build this should already be in the box. Most are connected to the components, others are by themselves.

Also, note that there are two lone red wires (one longer and one shorter) and two lone black wires (one longer and one shorter) in the box. Keep that in mind when reading the instructions.

—

Lone Wires

- Connect the longer lone red wire from Arduino 5V to power rail j.
- Connect the longer lone black wire from Arduino GND to ground rail j. (I usually use the GND closer to the Vin, but any ground is fine I think.)
- Connect the lone green wire from Arduino SCL (it’s on the right side of the Arduino) to clock rail j.
- Connect the lone orange wire from Arduino SDA to data rail j. (Color coding is not obeyed here; wire should be blue but I lost the blue wire. Maybe Abdulrahman took it by accident?)

Rotary Encoder

- Connect the red wire to power rail i.
- Connect the black wire to ground rail i.
- Connect the green wire to Arduino analog 3 (NOT the clock rail, even though it’s green).
- Connect the blue wire to Arduino analog 2 (NOT the data rail, even though it’s blue).
- Connect the yellow wire to Arduino digital 12 (this wire is for detecting presses on the rotary encoder).

LCD Screen

- Connect the red wire to power rail h.
- Connect the black wire to ground rail h.
- Connect the green wire to clock rail h (note that we skipped i; this is just for more space).
- Connect the blue wire to data rail h (note that we skipped i; this is just for more space).

TEA5767 Radio Module

- Connect the red wire to power rail g.
- Connect the black wire to ground rail g.
- Connect the green wire to clock rail f (note that we skipped g; this is just for more space).
- Connect the blue wire to data rail f (note that we skipped g; this is just for more space).

More Lone Wires

- Connect the shorter lone red wire from power rail f to power rail e.
- Connect the shorter lone black wire from ground rail f to ground rail e.

Amplifier

- Connect the red wire to power rail d (remember that the screw connectors are weak, so don’t yank too hard on the wires).
- Connect the black wire to ground rail d.
- Connect the speakers to the amplifier (if not already done).
- Connect the audio wire (the headphone type of wire) from the TEA5767 Radio Module (look underneath to find which port is the correct one; there is a speaker symbol indicating the right one) to the amplifier.

Joystick

- Connect the red wire to power rail c.
- Connect the black wire to ground rail c.
- Connect the middle yellow wire to Arduino analog 4.
- Connect the other yellow wire to Arduino analog 5.
- You can skip this next one: Connect the green wire to Arduino digital 11. (This wire is for detecting presses on the joystick; it can be skipped since we are no longer detecting joystick presses in the code. Also, even though the wire is green, it is not a clock wire).

Connect your Arduino to your computer or a battery and that’s it! The basic radio build should be complete! ☺

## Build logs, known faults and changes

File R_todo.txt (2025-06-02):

Maybe include wiring instructions somewhere?
Comments in the Arduino code? (What each part does)
HARDWARE.md: "List all the components used and document with descriptions"
CODE.md: "Describe the build process and explain how your code works using code snippets"
Recommendations

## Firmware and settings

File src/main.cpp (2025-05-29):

#include "RadioHeaders.h"

#define PIN_A A2
#define PIN_B A3
#define ENCODER_BUTTON 12
#define PIN_STICK_X A4
#define PIN_STICK_Y A5
#define STICK_BUTTON 11

RadioHandler handler;
RadioInput input;
RadioDisplay display;
RadioModule module;

void setup() {
  Wire.begin();
  Serial.begin(9600);

  input.Init(PIN_A, PIN_B, ENCODER_BUTTON, PIN_STICK_X, PIN_STICK_Y, STICK_BUTTON);
  display.Init(&handler);
  handler.Init();

  handler.CheckForPreset();
}

void loop() {
  static unsigned long lastTime;

  input.Tick();
  display.Tick();

  if (handler.state == Normal) {
    // if (input.KnobIsDown()) handler.SwitchBand();

    int joystickPosition = input.JoystickGetRegion();
    if (joystickPosition != 0) handler.TuneToPreset(joystickPosition);

    if (input.KnobIsLongPressed()) {
      handler.state = ChoosePreset;
      display.Clear();
      display.ScrollText(true, "Move  joystick  up,  right,  down,  or  left  to  choose  preset  to  overwrite");
    }

    int knobDirection = input.KnobGetDirection();
    bool updated = handler.UpdateCurrentFrequency(knobDirection);
    handler.CheckForPreset();

    if (updated) {
      display.PrintStationData();
      module.TuneTo(handler.band, handler.frequency);
    }
  }

  else if (handler.state == ChoosePreset) {
    int joystickPosition = input.JoystickGetRegion();

    if (joystickPosition != 0) {
      handler.state = PresetChosenConfirmation;
      handler.StorePresetStation(joystickPosition, handler.frequency);

      display.StopScrollText();
      display.Clear();

      display.PrintText(0, true, "Station saved!");

      char toPrint[15];
      sprintf(toPrint, "%s%d", "Preset: ", joystickPosition);
      display.PrintText(1, true, toPrint);

      lastTime = millis();
    }
  }

  else if (handler.state == PresetChosenConfirmation) {
    if ((signed long)millis() - (signed long)lastTime >= display.CONFIRMATION_TIME) {
      handler.state = Normal;
    }
  }
}

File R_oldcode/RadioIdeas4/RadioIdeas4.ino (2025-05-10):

#include <Wire.h>
#include "RadioHeaders.h"

#define PIN_A A2
#define PIN_B A3
#define ENCODER_BUTTON 12
#define PIN_STICK_X A4
#define PIN_STICK_Y A5
#define STICK_BUTTON 11

RadioHandler handler;
RadioInput input;
RadioDisplay display;
RadioModule module;

void setup() {
  Wire.begin();//kick off the I2C
  Serial.begin(9600);

  input.Init(PIN_A, PIN_B, ENCODER_BUTTON, PIN_STICK_X, PIN_STICK_Y, STICK_BUTTON);
  display.Init(&handler);

  display.PrintStationData();
}

void loop() {
  input.Tick();
  display.Tick();

  if (input.KnobIsDown()) handler.SwitchBand();

  int joystickPosition = input.JoystickGetRegion();
  Serial.print("joystick position ");
  Serial.println(joystickPosition);
  if (joystickPosition != 0) handler.TuneToPreset(joystickPosition);

  if (input.JoystickIsDown()) {
    // TODO
  }

  if (input.JoystickIsLongPressed()) {
    // TODO
  }

  int knobDirection = input.KnobGetDirection();
  bool updated = handler.UpdateCurrentFrequency(knobDirection);

  if (updated) {
    display.PrintStationData();
    module.TuneTo(handler.band, handler.frequency);
  }
}

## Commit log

2025-05-10 Integrated PlatformIO (Arduino support in VSCode)
2025-05-29 Less frequent standy saving, fixed bug
    [RadioHeaders.h, main.cpp]
2025-05-31 Added circuit diagram, moved things around
2025-06-01 Old Models Uploaded
    [Old Base.stl, Old Long Side (Back).stl, Old Short Side (Left).stl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]
2025-06-01 Little updates for model files
    [OldBase.stl, OldLongSideBack.stl, OldShortSideLeft.stl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]
2025-06-02 Added models and cropped images
    [Main_box_assembly.SLDASM, Main_box_assembly_part.SLDPRT, Main_box_assembly_part.STL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]
